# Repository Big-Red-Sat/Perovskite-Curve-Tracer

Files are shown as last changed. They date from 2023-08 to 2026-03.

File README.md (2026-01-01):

# Perovskite Curve Tracer
This project contains the hardware and software source for the curve tracer developed to evaluate perovskite solar cell samples during the [Big Red Sat-1 project](https://github.com/Big-Red-Sat/Big-Red-Sat-1).

## Hardware
The hardware is licensed under a CERN Open Hardware Licence Version 2 - Strongly Reciprocal license.  The developed hardware performs a passive curve tracing process that utilizes a low-Ohm resistor ladder, realized through analog switches and precision resistors.  The multiplexing of the perovskite solar cells is achieved through a low-Ohm analog SPDT relay.  Provisions are also made for an I2C connection to a temperature sensor on the sample holder.  A simple control interface is provisioned through USB for controlling the hardware and retrieve readings.

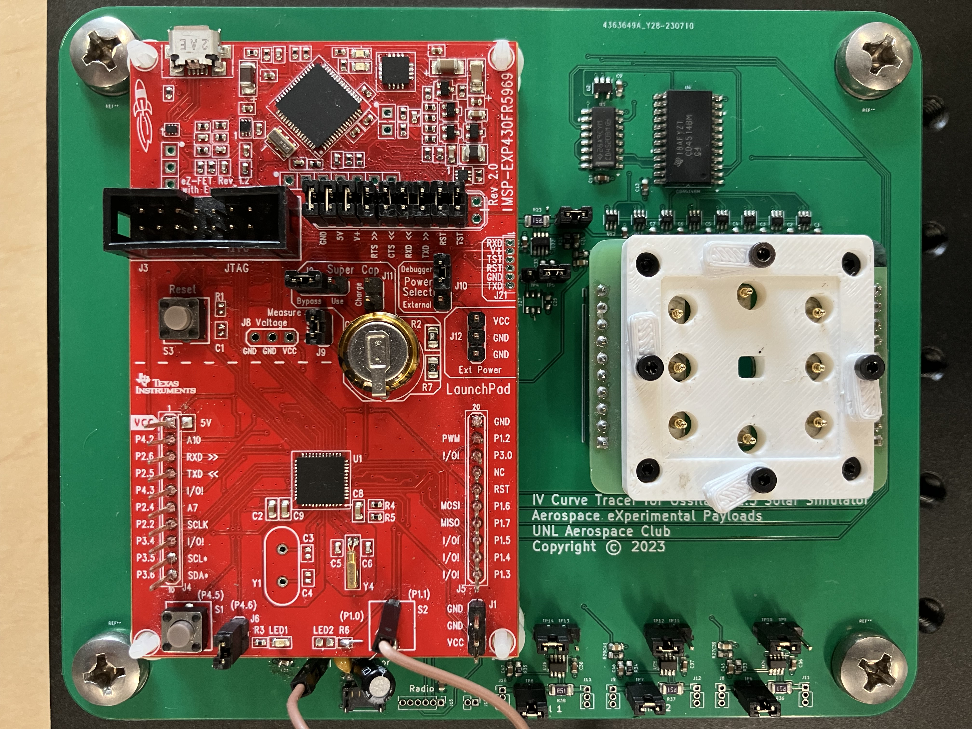
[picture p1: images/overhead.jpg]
Overhead hardware


## Software
The software is licensed under an MIT license.  The software is operated using a single Python script under the software directory, `curve_tracer.py`.  
1. Clone this repository to a local directory,
2. Create a Python 3.9 virtual environment in the software folder,
3. Install all packages using the requirements.txt file,
4. Run curve_tracer.py.

## Performance
The collected data can be saved to the software folder under a directory called curves.  In that folder are numerous experiments from the Big Red Sat-1 project.  The plotted curves will look like the image below.
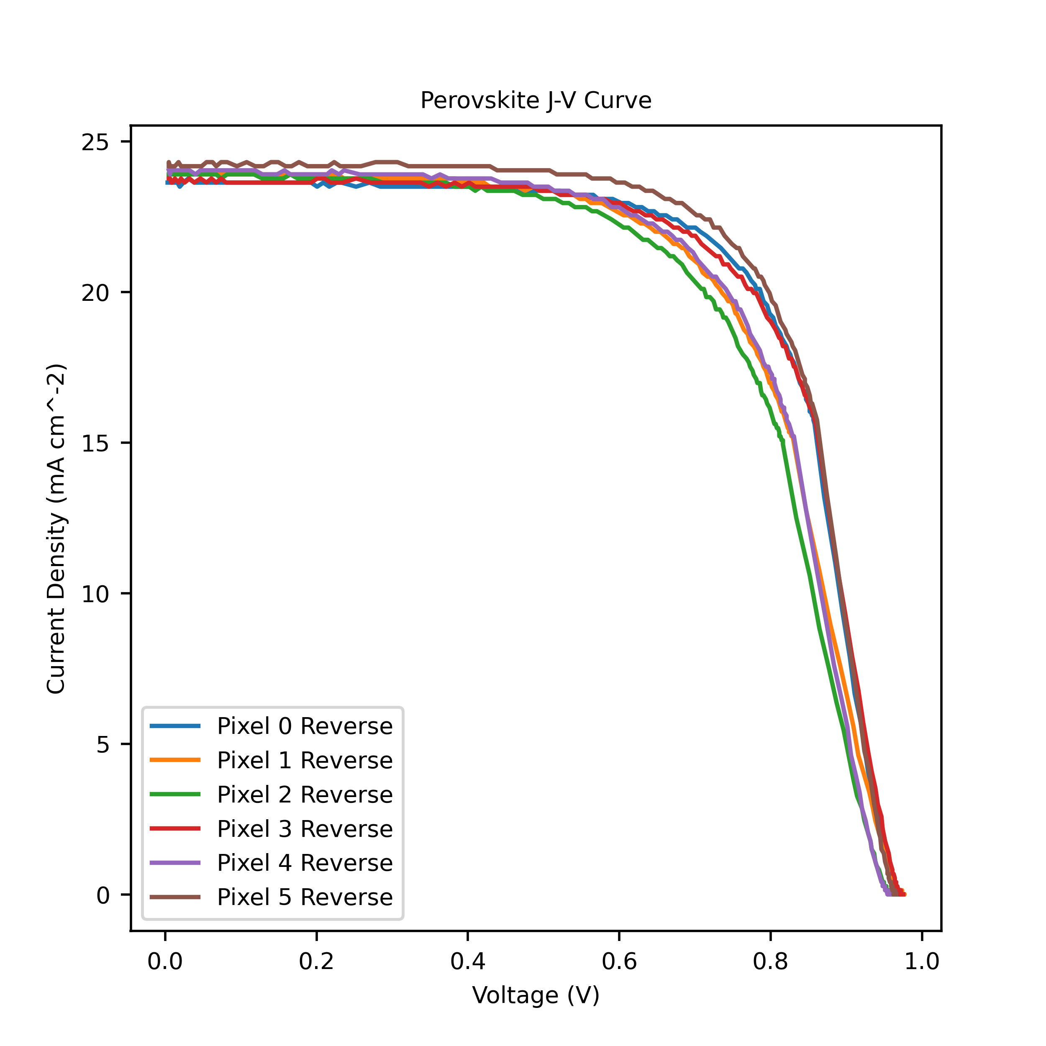
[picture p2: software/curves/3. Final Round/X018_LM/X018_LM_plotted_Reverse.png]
X018 Curve


## Citation
If this repository was useful to your research, then please cite this repository using the BibTeX definition below.
```
@software{
  Arce_Perovskite_Curve_Tracer_2023,
  author = {Arce, Walker},
  month = aug,
  title = {{Perovskite Curve Tracer}},
  url = {https://github.com/wsarce/Perovskite-Curve-Tracer},
  version = {v1.0.0},
  year = {2023}
}
```
## Contact
For additional information or questions, please contact Walker Arce (wsarcera@gmail.com).

## License
The hardware is licensed under a CERN Open Hardware Licence Version 2 - Strongly Reciprocal, the software and firmware is licensed under an MIT license, and the documentation is licensed under a Creative Commons Attribution-ShareAlike 4.0 International Public License.

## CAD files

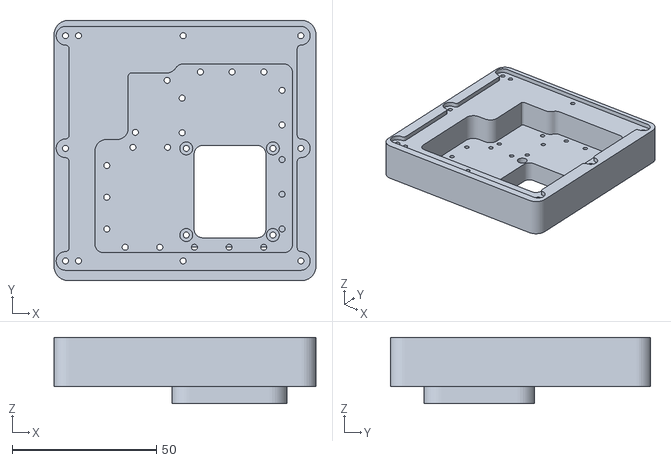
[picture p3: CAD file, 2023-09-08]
hardware/cell holder/Holder/payload_holder_p2.stl
90.7 x 90.2 x 23.0

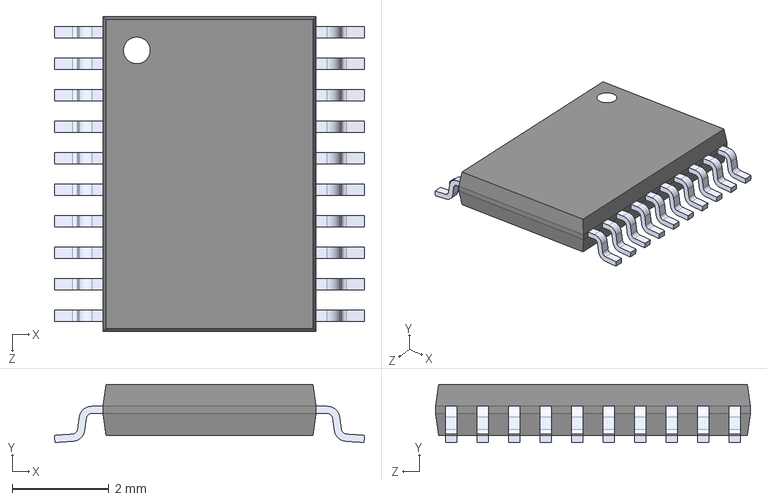
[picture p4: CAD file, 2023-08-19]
hardware/multiplexer cell tester/KiCAD Parts/ADS131M04IPWR/ADS131M04IPWR.step
6.40 x 1.20 x 6.50 mm

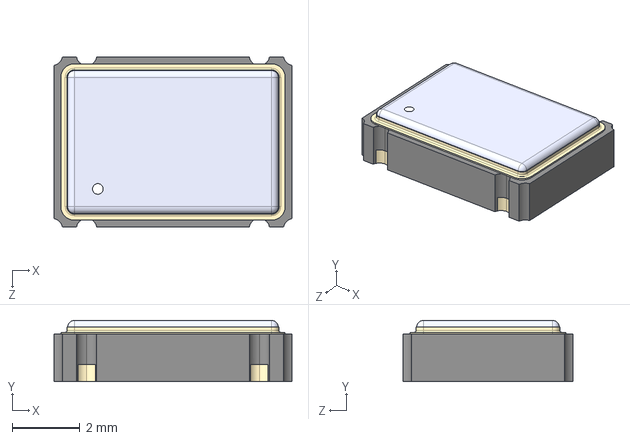
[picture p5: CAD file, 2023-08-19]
hardware/multiplexer cell tester/KiCAD Parts/CB3LV-3I-8M1920/CB3LV-3I-8M1920.step
7.00 x 1.80 x 5.00 mm

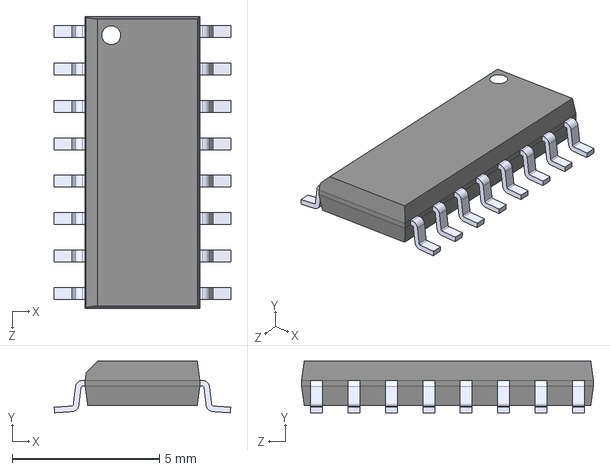
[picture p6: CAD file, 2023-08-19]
hardware/multiplexer cell tester/KiCAD Parts/CD4028BMT/CD4028BMT.step
5.99 x 1.75 x 9.91 mm

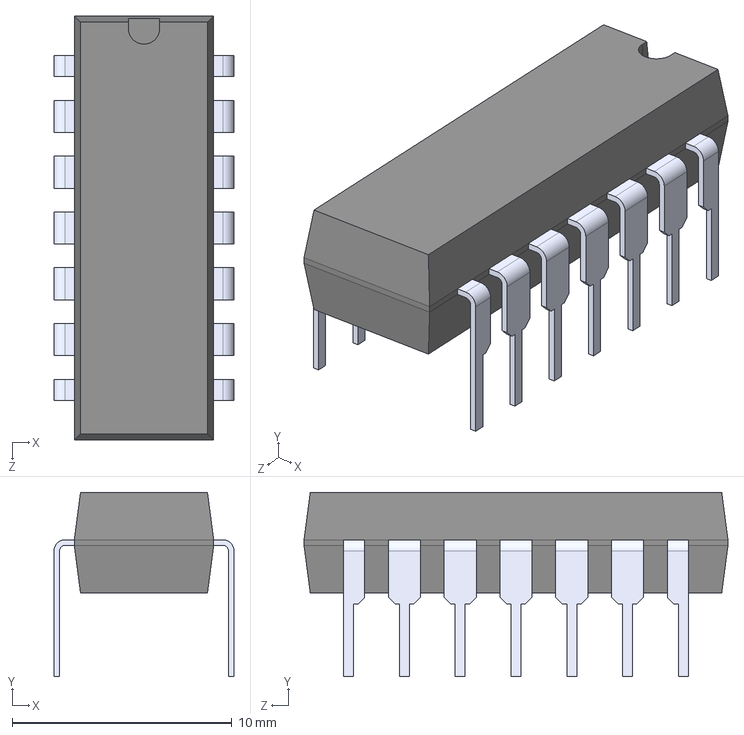
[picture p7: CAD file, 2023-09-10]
hardware/multiplexer cell tester/KiCAD Parts/CD4071BE/CD4071BE.step
8.19 x 8.38 x 19.3 mm

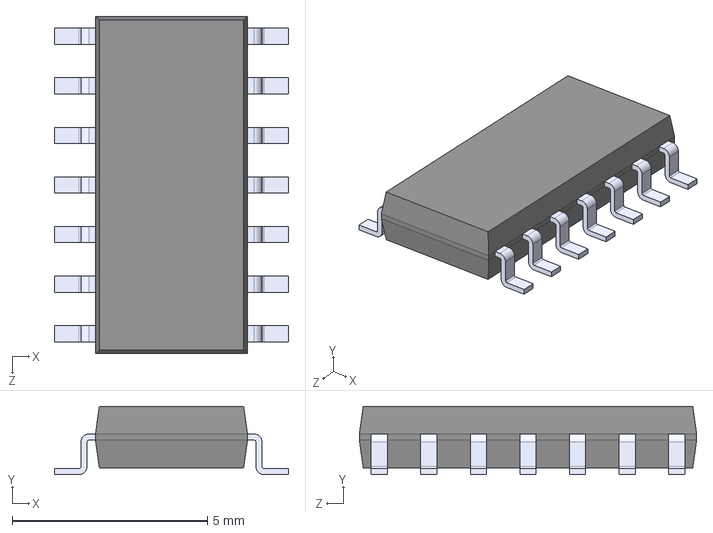
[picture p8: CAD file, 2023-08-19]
hardware/multiplexer cell tester/KiCAD Parts/CD4072BM/CD4072BM.step
6.00 x 1.75 x 8.65 mm

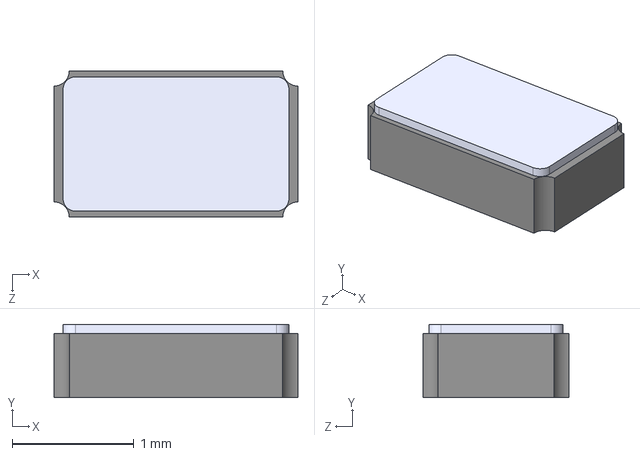
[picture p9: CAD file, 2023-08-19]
hardware/multiplexer cell tester/KiCAD Parts/CM8V-T1A-32.768KHZ-7PF-20PPM-TA-QC/CM8V-T1A-32.768KHZ-7PF-20PPM-TA-QC.step
2.00 x 0.6 x 1.20 mm

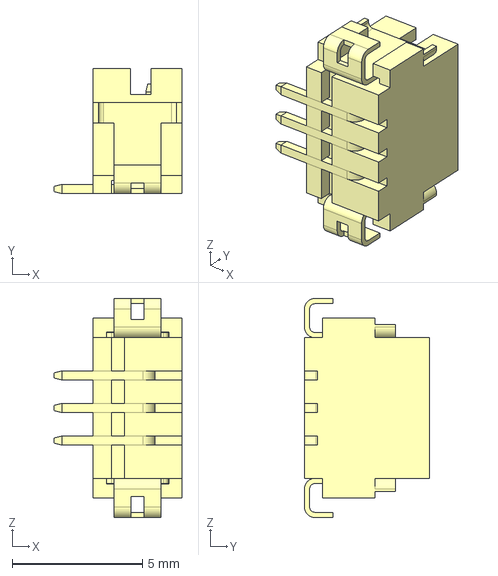
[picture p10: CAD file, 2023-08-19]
hardware/multiplexer cell tester/KiCAD Parts/DF13C-3P-1.25V_21_/WNCW-1600324.stp
4.90 x 4.80 x 8.40 mm

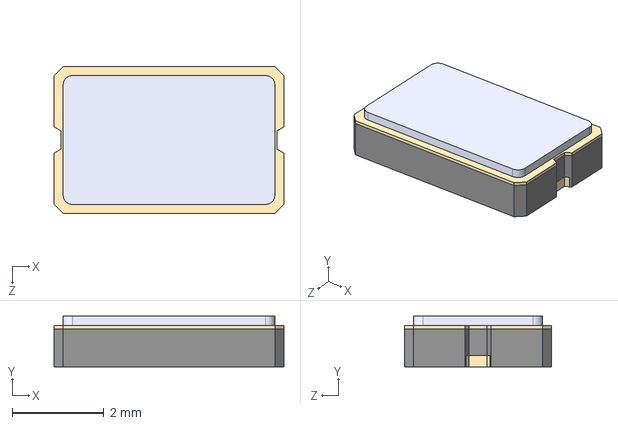
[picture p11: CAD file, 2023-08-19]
hardware/multiplexer cell tester/KiCAD Parts/ECS-81.92-12-30Q-EN-TR/ECS-81.92-12-30Q-EN-TR.step
5.00 x 1.10 x 3.20 mm

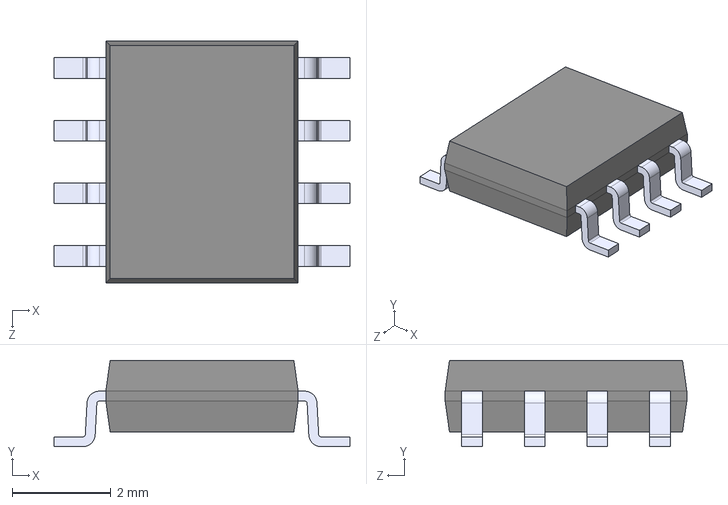
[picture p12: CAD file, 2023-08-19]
hardware/multiplexer cell tester/KiCAD Parts/ICL7660CSAT/ICL7660CSAT.step
6.00 x 1.75 x 4.90 mm

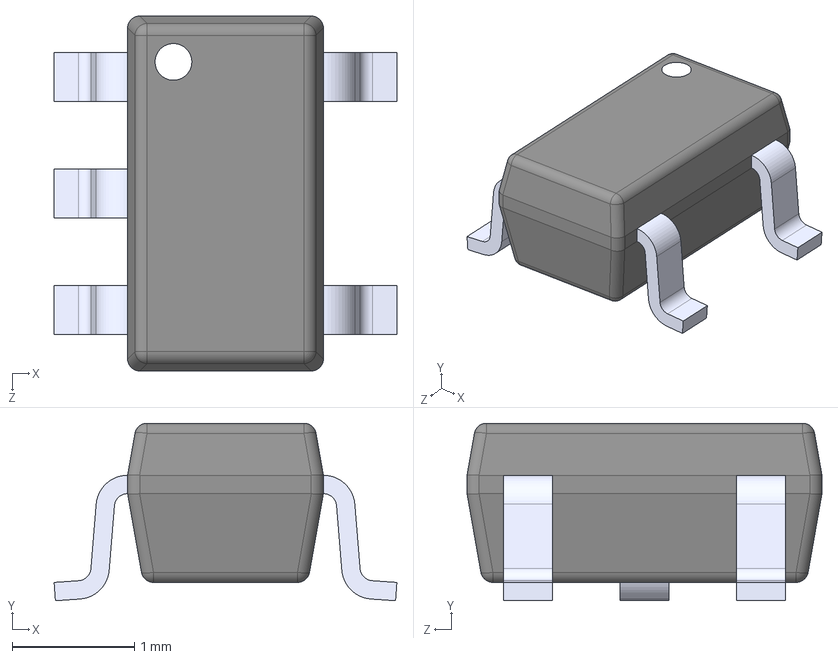
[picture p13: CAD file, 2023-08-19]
hardware/multiplexer cell tester/KiCAD Parts/INA180B2IDBVT/INA180B2IDBVT.step
2.80 x 1.45 x 2.90 mm

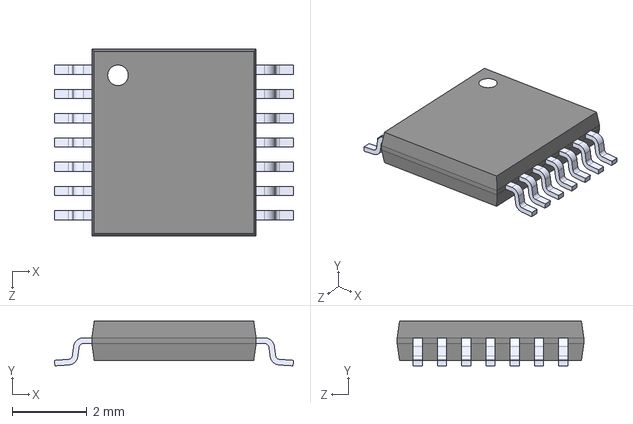
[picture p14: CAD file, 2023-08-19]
hardware/multiplexer cell tester/KiCAD Parts/INA4180A4IPWR/INA4180A4IPWR.step
6.40 x 1.20 x 5.00 mm

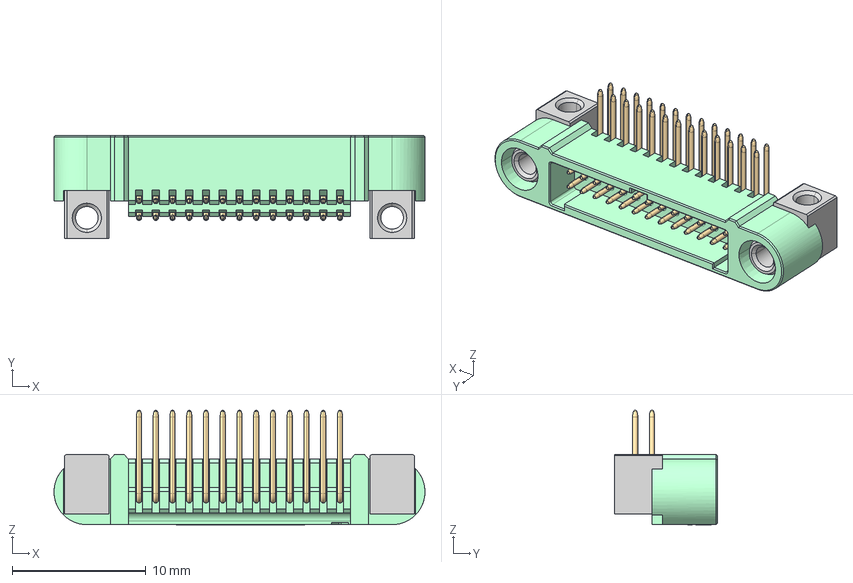
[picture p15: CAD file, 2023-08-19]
hardware/multiplexer cell tester/KiCAD Parts/LIB_G125-MH12605M4R/G125-MH12605M4R.stp
27.7 x 7.70 x 8.55 mm
G125-3272696
G125-4640000 x 2
G125-1060005_BENT x 13
G125-1070005_BENT x 13

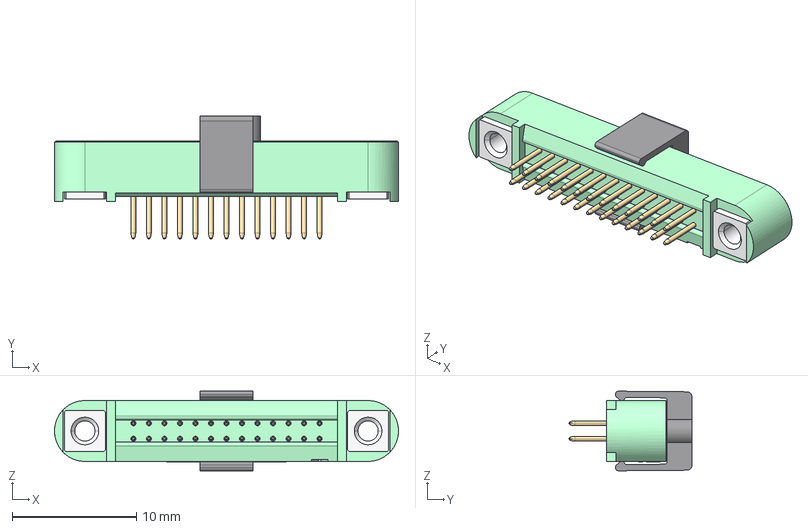
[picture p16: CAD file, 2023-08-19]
hardware/multiplexer cell tester/KiCAD Parts/LIB_G125-MV12605M1P/G125-MV12605M1P.stp
27.7 x 9.90 x 6.41 mm
G125-3212696
G125-1030000 x 26
G125-5000098_CAP_AF5
G125-4620000 x 2
G125_LASER_HARWIN

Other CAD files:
hardware/multiplexer cell tester/KiCAD Parts/LT3092EDD_TRPBF/LT3092EDD_TRPBF.step
hardware/multiplexer cell tester/KiCAD Parts/LT3092ETS8TRPBF/LT3092ETS8TRPBF.step
hardware/multiplexer cell tester/KiCAD Parts/MAX4736EUBT/MAX4736EUBT.step
hardware/multiplexer cell tester/KiCAD Parts/MSP430FR5969IRGZR/MSP430FR5969IRGZR.step
hardware/cell holder/Holder/arm.step
hardware/cell holder/Holder/arm_v2.stl
hardware/cell holder/Holder/body.step
hardware/cell holder/Holder/body_v2.stl
hardware/cell holder/Holder/payload_holder_p1.stl
hardware/cell holder/Holder/payload_holder_p3.stl
hardware/multiplexer cell tester/KiCAD Parts/0781710004/0781710004.step
hardware/multiplexer cell tester/KiCAD Parts/NX3L4051PW_118/NX3L4051PW_118.step
hardware/multiplexer cell tester/KiCAD Parts/ul_ADG841YKSZ-500RL7/SC70-3.iges
hardware/multiplexer cell tester/KiCAD Parts/ul_ADG841YKSZ-500RL7/SC70-3.step
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

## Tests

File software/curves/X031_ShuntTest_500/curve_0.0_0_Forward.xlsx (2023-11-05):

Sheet: Summary
 | 0
Time | 2023-10-22 16:01
ID | X031_ShuntTest_500
Pixel | 0
Pixel Area | 0.058
Irradiance | 100
Panel Temperature | 0
Voc | 0.004820512821
Isc | 2.552036199
Vmp | 0.4675897436
Imp | 1.283894754
Pmp | 0.600336019
FF | 48.79898604
Eff | 0.1035062102
Dir | Forward

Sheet: Data
 | Voltage | Current | Current Density | Power
0 | 0.004820512821 | 2.961622256 | 51.06245269 | 0.01427653805
1 | 0.08837606838 | 2.512652924 | 43.32160215 | 0.2220583867
2 | 0.1638974359 | 2.134573488 | 36.80299116 | 0.3498511213
3 | 0.2265641026 | 1.8352606 | 31.64242414 | 0.4158041708
4 | 0.2795897436 | 1.567454332 | 27.02507469 | 0.4382441548
5 | 0.3245811966 | 1.354784649 | 23.35835602 | 0.4397376225
6 | 0.3631452991 | 1.16574493 | 20.09905053 | 0.4233347915
7 | 0.3952820513 | 1.000335177 | 17.24715822 | 0.3954145407
8 | 0.4242051282 | 0.858555388 | 14.8026791 | 0.3642035984
9 | 0.4483076923 | 0.7482822189 | 12.90141757 | 0.3354606747
10 | 0.4708034188 | 0.6380090498 | 11.00015603 | 0.3003768419
11 | 0.4884786325 | 0.5513658455 | 9.506307681 | 0.2693304342
12 | 0.5061538462 | 0.4804759511 | 8.284068122 | 0.2431947506
13 | 0.519008547 | 0.4095860566 | 7.061828563 | 0.2125786641
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

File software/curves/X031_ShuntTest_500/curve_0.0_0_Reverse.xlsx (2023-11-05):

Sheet: Summary
 | 0
Time | 2023-10-22 16:00
ID | X031_ShuntTest_500
Pixel | 0
Pixel Area | 0.058
Irradiance | 100
Panel Temperature | 0
Voc | 0.006427350427
Isc | 0
Vmp | 0.4322393162
Imp | 1.205128205
Pmp | 0.5209037914
FF | 5209037.914
Eff | 0.08981099851
Dir | Reverse

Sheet: Data
 | Voltage | Current | Current Density | Power
0 | 0.006427350427 | 2.953745601 | 50.92664829 | 0.01898475805
1 | 0.008034188034 | 2.945868946 | 50.79084389 | 0.02366766504
2 | 0.01124786325 | 2.922238981 | 50.38343071 | 0.03286894444
3 | 0.01606837607 | 2.898609016 | 49.97601752 | 0.04657593975
4 | 0.0241025641 | 2.867102397 | 49.43279994 | 0.0691045193
5 | 0.03052991453 | 2.827719122 | 48.75377796 | 0.0863300231
6 | 0.03856410256 | 2.788335847 | 48.07475599 | 0.1075296696
7 | 0.0465982906 | 2.748952572 | 47.39573401 | 0.1280964908
8 | 0.05945299145 | 2.678062678 | 46.17349445 | 0.1592188375
9 | 0.06909401709 | 2.622926094 | 45.22286368 | 0.1812285003
10 | 0.08034188034 | 2.559912854 | 44.13642852 | 0.2056682122
11 | 0.08998290598 | 2.504776269 | 43.18579775 | 0.2253870476
12 | 0.09962393162 | 2.449639685 | 42.23516698 | 0.2440427365
13 | 0.1076581197 | 2.3945031 | 41.28453621 | 0.2577877013
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

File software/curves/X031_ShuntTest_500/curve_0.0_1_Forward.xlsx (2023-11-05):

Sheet: Summary
 | 0
Time | 2023-10-22 16:01
ID | X031_ShuntTest_500
Pixel | 1
Pixel Area | 0.058
Irradiance | 100
Panel Temperature | 0
Voc | 0.6475555556
Isc | 2.599296129
Vmp | 0.5093675214
Imp | 1.291771409
Pmp | 0.657986401
FF | 0.390916587
Eff | 0.1134459312
Dir | Forward

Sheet: Data
 | Voltage | Current | Current Density | Power
0 | 0.6475555556 | 0.03150661974 | 0.5432175818 | 0.02040228665
1 | 0.6491623932 | 0.03150661974 | 0.5432175818 | 0.02045291267
2 | 0.6523760684 | 0.02362996481 | 0.4074131863 | 0.01541562354
3 | 0.653982906 | 0.02362996481 | 0.4074131863 | 0.01545359305
4 | 0.6571965812 | 0.01575330987 | 0.2716087909 | 0.01035302139
5 | 0.6588034188 | 0.02362996481 | 0.4074131863 | 0.0155675016
6 | 0.6604102564 | 0.02362996481 | 0.4074131863 | 0.01560547112
7 | 0.662017094 | 0.01575330987 | 0.2716087909 | 0.01042896042
8 | 0.6636239316 | 0.01575330987 | 0.2716087909 | 0.01045427343
9 | 0.6652307692 | 0.01575330987 | 0.2716087909 | 0.01047958644
10 | 0.6668376068 | 0.007876654935 | 0.1358043954 | 0.005252449727
11 | 0.6668376068 | 0.007876654935 | 0.1358043954 | 0.005252449727
12 | 0.6684444444 | 0.007876654935 | 0.1358043954 | 0.005265106232
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

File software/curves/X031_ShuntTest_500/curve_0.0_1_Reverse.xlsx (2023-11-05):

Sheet: Summary
 | 0
Time | 2023-10-22 16:00
ID | X031_ShuntTest_500
Pixel | 1
Pixel Area | 0.058
Irradiance | 100
Panel Temperature | 0
Voc | 0.006427350427
Isc | 0
Vmp | 0.4949059829
Imp | 1.220881515
Pmp | 0.6042215662
FF | 6042215.662
Eff | 0.1041761321
Dir | Reverse

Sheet: Data
 | Voltage | Current | Current Density | Power
0 | 0.006427350427 | 2.922238981 | 50.38343071 | 0.01878225396
1 | 0.008034188034 | 2.914362326 | 50.24762631 | 0.02341453493
2 | 0.01285470085 | 2.898609016 | 49.97601752 | 0.0372607518
3 | 0.01767521368 | 2.874979051 | 49.56860434 | 0.05081586905
4 | 0.0241025641 | 2.835595777 | 48.88958236 | 0.06834512898
5 | 0.03052991453 | 2.804089157 | 48.34636478 | 0.0856086023
6 | 0.03695726496 | 2.764705882 | 47.6673428 | 0.1021759678
7 | 0.0465982906 | 2.717445953 | 46.85251643 | 0.1266283362
8 | 0.05784615385 | 2.654432713 | 45.76608126 | 0.1535487231
9 | 0.06748717949 | 2.591419474 | 44.6796461 | 0.1748875912
10 | 0.07873504274 | 2.528406234 | 43.59321094 | 0.1990741729
11 | 0.08837606838 | 2.47326965 | 42.64258017 | 0.2185778477
12 | 0.09801709402 | 2.418133065 | 41.6919494 | 0.237018376
13 | 0.1060512821 | 2.362996481 | 40.74131863 | 0.2505988063
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

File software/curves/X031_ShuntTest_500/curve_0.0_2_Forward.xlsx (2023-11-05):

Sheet: Summary
 | 0
Time | 2023-10-22 16:01
ID | X031_ShuntTest_500
Pixel | 2
Pixel Area | 0.058
Irradiance | 100
Panel Temperature | 0
Voc | 0.6330940171
Isc | 2.615049439
Vmp | 0.4788376068
Imp | 1.268141445
Pmp | 0.6072338145
FF | 0.3667818261
Eff | 0.1046954853
Dir | Forward

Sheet: Data
 | Voltage | Current | Current Density | Power
0 | 0.6330940171 | 0 | 0 | 0
1 | 0.6314871795 | 0 | 0 | 0
2 | 0.6298803419 | 0 | 0 | 0
3 | 0.6298803419 | 0 | 0 | 0
4 | 0.6298803419 | 0 | 0 | 0
5 | 0.6298803419 | 0 | 0 | 0
6 | 0.6282735043 | 0 | 0 | 0
7 | 0.6282735043 | 0.007876654935 | 0.1358043954 | 0.004948693598
8 | 0.6282735043 | 0 | 0 | 0
9 | 0.6282735043 | 0 | 0 | 0
10 | 0.6282735043 | 0 | 0 | 0
11 | 0.6282735043 | 0 | 0 | 0
12 | 0.6282735043 | 0 | 0 | 0
13 | 0.6282735043 | 0 | 0 | 0
14 | 0.6282735043 | 0 | 0 | 0
15 | 0.6282735043 | 0.007876654935 | 0.1358043954 | 0.004948693598
16 | 0.6298803419 | 0 | 0 | 0
17 | 0.6282735043 | 0 | 0 | 0
18 | 0.6282735043 | 0 | 0 | 0
19 | 0.6298803419 | 0 | 0 | 0
20 | 0.6298803419 | 0 | 0 | 0
21 | 0.6298803419 | 0 | 0 | 0
22 | 0.6298803419 | 0 | 0 | 0
23 | 0.6298803419 | 0 | 0 | 0
24 | 0.6298803419 | 0 | 0 | 0
25 | 0.6298803419 | 0 | 0 | 0
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

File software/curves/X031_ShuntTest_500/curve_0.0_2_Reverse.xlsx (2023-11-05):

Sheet: Summary
 | 0
Time | 2023-10-22 16:00
ID | X031_ShuntTest_500
Pixel | 2
Pixel Area | 0.058
Irradiance | 100
Panel Temperature | 0
Voc | 0.006427350427
Isc | 0
Vmp | 0.4531282051
Imp | 1.21300486
Pmp | 0.5496467151
FF | 5496467.151
Eff | 0.09476667501
Dir | Reverse

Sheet: Data
 | Voltage | Current | Current Density | Power
0 | 0.006427350427 | 2.945868946 | 50.79084389 | 0.01893413203
1 | 0.009641025641 | 2.937992291 | 50.6550395 | 0.02832525901
2 | 0.01124786325 | 2.922238981 | 50.38343071 | 0.03286894444
3 | 0.01767521368 | 2.890732361 | 49.84021313 | 0.05109431216
4 | 0.0241025641 | 2.867102397 | 49.43279994 | 0.0691045193
5 | 0.03213675214 | 2.827719122 | 48.75377796 | 0.09087370853
6 | 0.03856410256 | 2.788335847 | 48.07475599 | 0.1075296696
7 | 0.0465982906 | 2.756829227 | 47.5315384 | 0.1284635295
8 | 0.05784615385 | 2.685939333 | 46.30929884 | 0.1553712599
9 | 0.06909401709 | 2.630802748 | 45.35866808 | 0.1817727301
10 | 0.08034188034 | 2.575666164 | 44.40803731 | 0.2069338627
11 | 0.08998290598 | 2.520529579 | 43.45740654 | 0.2268045762
12 | 0.1012307692 | 2.465392995 | 42.50677577 | 0.2495736293
13 | 0.1092649573 | 2.41025641 | 41.556145 | 0.2633565637
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

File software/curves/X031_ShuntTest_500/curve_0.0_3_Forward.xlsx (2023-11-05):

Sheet: Summary
 | 0
Time | 2023-10-22 16:01
ID | X031_ShuntTest_500
Pixel | 3
Pixel Area | 0.058
Irradiance | 100
Panel Temperature | 0
Voc | 0.4804444444
Isc | 1.961287079
Vmp | 0.151042735
Imp | 1.26026479
Pmp | 0.1903538407
FF | 0.2020120402
Eff | 0.03281962771
Dir | Forward

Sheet: Data
 | Voltage | Current | Current Density | Power
0 | 0.4804444444 | 0 | 0 | 0
1 | 0.474017094 | 0.007876654935 | 0.1358043954 | 0.003733669083
2 | 0.4691965812 | 0 | 0 | 0
3 | 0.465982906 | 0 | 0 | 0
4 | 0.4611623932 | 0 | 0 | 0
5 | 0.4579487179 | 0 | 0 | 0
6 | 0.4547350427 | 0 | 0 | 0
7 | 0.4531282051 | 0 | 0 | 0
8 | 0.4515213675 | 0 | 0 | 0
9 | 0.4499145299 | 0 | 0 | 0
10 | 0.4483076923 | 0 | 0 | 0
11 | 0.4467008547 | 0 | 0 | 0
12 | 0.4467008547 | 0 | 0 | 0
13 | 0.4450940171 | 0 | 0 | 0
14 | 0.4434871795 | 0 | 0 | 0
15 | 0.4434871795 | 0.007876654935 | 0.1358043954 | 0.003493195481
16 | 0.4434871795 | 0 | 0 | 0
17 | 0.4418803419 | 0 | 0 | 0
18 | 0.4418803419 | 0 | 0 | 0
19 | 0.4418803419 | 0 | 0 | 0
20 | 0.4418803419 | 0 | 0 | 0
21 | 0.4402735043 | 0.007876654935 | 0.1358043954 | 0.00346788247
22 | 0.4402735043 | 0 | 0 | 0
23 | 0.4402735043 | 0 | 0 | 0
24 | 0.4402735043 | 0 | 0 | 0
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

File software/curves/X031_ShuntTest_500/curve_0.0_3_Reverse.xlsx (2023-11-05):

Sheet: Summary
 | 0
Time | 2023-10-22 16:00
ID | X031_ShuntTest_500
Pixel | 3
Pixel Area | 0.058
Irradiance | 100
Panel Temperature | 0
Voc | 0.004820512821
Isc | 0
Vmp | 0.1462222222
Imp | 1.19725155
Pmp | 0.1750647822
FF | 1750647.822
Eff | 0.03018358314
Dir | Reverse

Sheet: Data
 | Voltage | Current | Current Density | Power
0 | 0.004820512821 | 2.3945031 | 41.28453621 | 0.01154273289
1 | 0.006427350427 | 2.370873136 | 40.87712303 | 0.01523843246
2 | 0.009641025641 | 2.339366516 | 40.33390545 | 0.02255389256
3 | 0.01285470085 | 2.299983241 | 39.65488347 | 0.02956559654
4 | 0.01767521368 | 2.252723312 | 38.8400571 | 0.03981736588
5 | 0.0224957265 | 2.213340037 | 38.16103512 | 0.04979069211
6 | 0.02892307692 | 2.166080107 | 37.34620875 | 0.06264970156
7 | 0.03535042735 | 2.118820178 | 36.53138237 | 0.07490119876
8 | 0.04177777778 | 2.055806938 | 35.44494721 | 0.08588704542
9 | 0.05141880342 | 2.000670354 | 34.49431644 | 0.1028720756
10 | 0.05784615385 | 1.937657114 | 33.40788128 | 0.1120860115
11 | 0.06588034188 | 1.88252053 | 32.45725051 | 0.1240210961
12 | 0.0707008547 | 1.8352606 | 31.64242414 | 0.129754493
13 | 0.07712820513 | 1.780124015 | 30.69179337 | 0.1372977702
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

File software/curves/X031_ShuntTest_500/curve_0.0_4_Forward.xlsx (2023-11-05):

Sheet: Summary
 | 0
Time | 2023-10-22 16:01
ID | X031_ShuntTest_500
Pixel | 4
Pixel Area | 0.058
Irradiance | 100
Panel Temperature | 0
Voc | 0.4370598291
Isc | 1.961287079
Vmp | 0.1397948718
Imp | 1.354784649
Pmp | 0.1893919463
FF | 0.2209425681
Eff | 0.03265378385
Dir | Forward

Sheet: Data
 | Voltage | Current | Current Density | Power
0 | 0.4370598291 | 0 | 0 | 0
1 | 0.4370598291 | 0 | 0 | 0
2 | 0.4370598291 | 0.007876654935 | 0.1358043954 | 0.00344256946
3 | 0.4370598291 | 0 | 0 | 0
4 | 0.4370598291 | 0 | 0 | 0
5 | 0.4370598291 | 0 | 0 | 0
6 | 0.4370598291 | 0 | 0 | 0
7 | 0.4370598291 | 0 | 0 | 0
8 | 0.4370598291 | 0 | 0 | 0
9 | 0.4370598291 | 0 | 0 | 0
10 | 0.4370598291 | 0 | 0 | 0
11 | 0.4370598291 | 0 | 0 | 0
12 | 0.4386666667 | 0 | 0 | 0
13 | 0.4370598291 | 0 | 0 | 0
14 | 0.4370598291 | 0 | 0 | 0
15 | 0.4370598291 | 0 | 0 | 0
16 | 0.4370598291 | 0 | 0 | 0
17 | 0.4370598291 | 0 | 0 | 0
18 | 0.4370598291 | 0 | 0 | 0
19 | 0.4370598291 | 0 | 0 | 0
20 | 0.4370598291 | 0 | 0 | 0
21 | 0.4370598291 | 0 | 0 | 0
22 | 0.4370598291 | 0 | 0 | 0
23 | 0.4370598291 | 0 | 0 | 0
24 | 0.4370598291 | 0 | 0 | 0
25 | 0.4386666667 | 0 | 0 | 0
26 | 0.4386666667 | 0 | 0 | 0
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

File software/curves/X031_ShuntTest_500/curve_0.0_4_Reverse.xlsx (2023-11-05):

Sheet: Summary
 | 0
Time | 2023-10-22 16:00
ID | X031_ShuntTest_500
Pixel | 4
Pixel Area | 0.058
Irradiance | 100
Panel Temperature | 0
Voc | 0.004820512821
Isc | 0
Vmp | 0.1381880342
Imp | 1.268141445
Pmp | 0.1752419733
FF | 1752419.733
Eff | 0.03021413333
Dir | Reverse

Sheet: Data
 | Voltage | Current | Current Density | Power
0 | 0.004820512821 | 2.292106586 | 39.51907907 | 0.01104912918
1 | 0.006427350427 | 2.284229931 | 39.38327468 | 0.01468154623
2 | 0.009641025641 | 2.260599966 | 38.97586149 | 0.02179450224
3 | 0.01285470085 | 2.236970002 | 38.5684483 | 0.02875558019
4 | 0.01767521368 | 2.197586727 | 37.88942633 | 0.03884281497
5 | 0.0224957265 | 2.166080107 | 37.34620875 | 0.04872754566
6 | 0.02892307692 | 2.126696833 | 36.66718677 | 0.06151061608
7 | 0.03535042735 | 2.079436903 | 35.8523604 | 0.07350898317
8 | 0.04338461538 | 2.024300318 | 34.90172963 | 0.08782349074
9 | 0.04981196581 | 1.969163734 | 33.95109886 | 0.09808791659
10 | 0.05784615385 | 1.914027149 | 33.00046809 | 0.1107191089
11 | 0.06588034188 | 1.858890565 | 32.04983732 | 0.1224643459
12 | 0.07230769231 | 1.811630635 | 31.23501095 | 0.1309948305
13 | 0.07712820513 | 1.764370706 | 30.42018458 | 0.1360827457
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

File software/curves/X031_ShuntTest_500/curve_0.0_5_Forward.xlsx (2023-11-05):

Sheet: Summary
 | 0
Time | 2023-10-22 16:01
ID | X031_ShuntTest_500
Pixel | 5
Pixel Area | 0.058
Irradiance | 100
Panel Temperature | 0
Voc | 0.4370598291
Isc | 1.961287079
Vmp | 0.1558632479
Imp | 1.220881515
Pmp | 0.1902905582
FF | 0.2219908789
Eff | 0.03280871693
Dir | Forward

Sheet: Data
 | Voltage | Current | Current Density | Power
0 | 0.4370598291 | 0 | 0 | 0
1 | 0.4370598291 | 0.007876654935 | 0.1358043954 | 0.00344256946
2 | 0.4370598291 | 0 | 0 | 0
3 | 0.4370598291 | 0 | 0 | 0
4 | 0.4370598291 | 0 | 0 | 0
5 | 0.4370598291 | 0 | 0 | 0
6 | 0.4370598291 | 0 | 0 | 0
7 | 0.4370598291 | 0 | 0 | 0
8 | 0.4386666667 | 0 | 0 | 0
9 | 0.4370598291 | 0 | 0 | 0
10 | 0.4370598291 | 0 | 0 | 0
11 | 0.4386666667 | 0 | 0 | 0
12 | 0.4370598291 | 0 | 0 | 0
13 | 0.4386666667 | 0 | 0 | 0
14 | 0.4370598291 | 0 | 0 | 0
15 | 0.4386666667 | 0 | 0 | 0
16 | 0.4370598291 | 0 | 0 | 0
17 | 0.4386666667 | 0 | 0 | 0
18 | 0.4386666667 | 0 | 0 | 0
19 | 0.4386666667 | 0 | 0 | 0
20 | 0.4370598291 | 0 | 0 | 0
21 | 0.4386666667 | 0 | 0 | 0
22 | 0.4370598291 | 0 | 0 | 0
23 | 0.4370598291 | 0 | 0 | 0
24 | 0.4386666667 | 0 | 0 | 0
25 | 0.4386666667 | 0 | 0 | 0
26 | 0.4386666667 | 0 | 0 | 0
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

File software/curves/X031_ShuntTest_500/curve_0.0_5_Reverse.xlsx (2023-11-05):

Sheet: Summary
 | 0
Time | 2023-10-22 16:00
ID | X031_ShuntTest_500
Pixel | 5
Pixel Area | 0.058
Irradiance | 100
Panel Temperature | 0
Voc | 0.004820512821
Isc | 0
Vmp | 0.143008547
Imp | 1.22875817
Pmp | 0.1757229205
FF | 1757229.205
Eff | 0.03029705526
Dir | Reverse

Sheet: Data
 | Voltage | Current | Current Density | Power
0 | 0.004820512821 | 2.292106586 | 39.51907907 | 0.01104912918
1 | 0.006427350427 | 2.284229931 | 39.38327468 | 0.01468154623
2 | 0.009641025641 | 2.260599966 | 38.97586149 | 0.02179450224
3 | 0.01285470085 | 2.236970002 | 38.5684483 | 0.02875558019
4 | 0.01767521368 | 2.197586727 | 37.88942633 | 0.03884281497
5 | 0.0224957265 | 2.166080107 | 37.34620875 | 0.04872754566
6 | 0.02892307692 | 2.126696833 | 36.66718677 | 0.06151061608
7 | 0.03535042735 | 2.087313558 | 35.98816479 | 0.07378742629
8 | 0.04338461538 | 2.024300318 | 34.90172963 | 0.08782349074
9 | 0.04981196581 | 1.969163734 | 33.95109886 | 0.09808791659
10 | 0.05784615385 | 1.914027149 | 33.00046809 | 0.1107191089
11 | 0.06427350427 | 1.86676722 | 32.18564172 | 0.1199836709
12 | 0.0707008547 | 1.811630635 | 31.23501095 | 0.1280838343
13 | 0.07873504274 | 1.764370706 | 30.42018458 | 0.1389178029
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

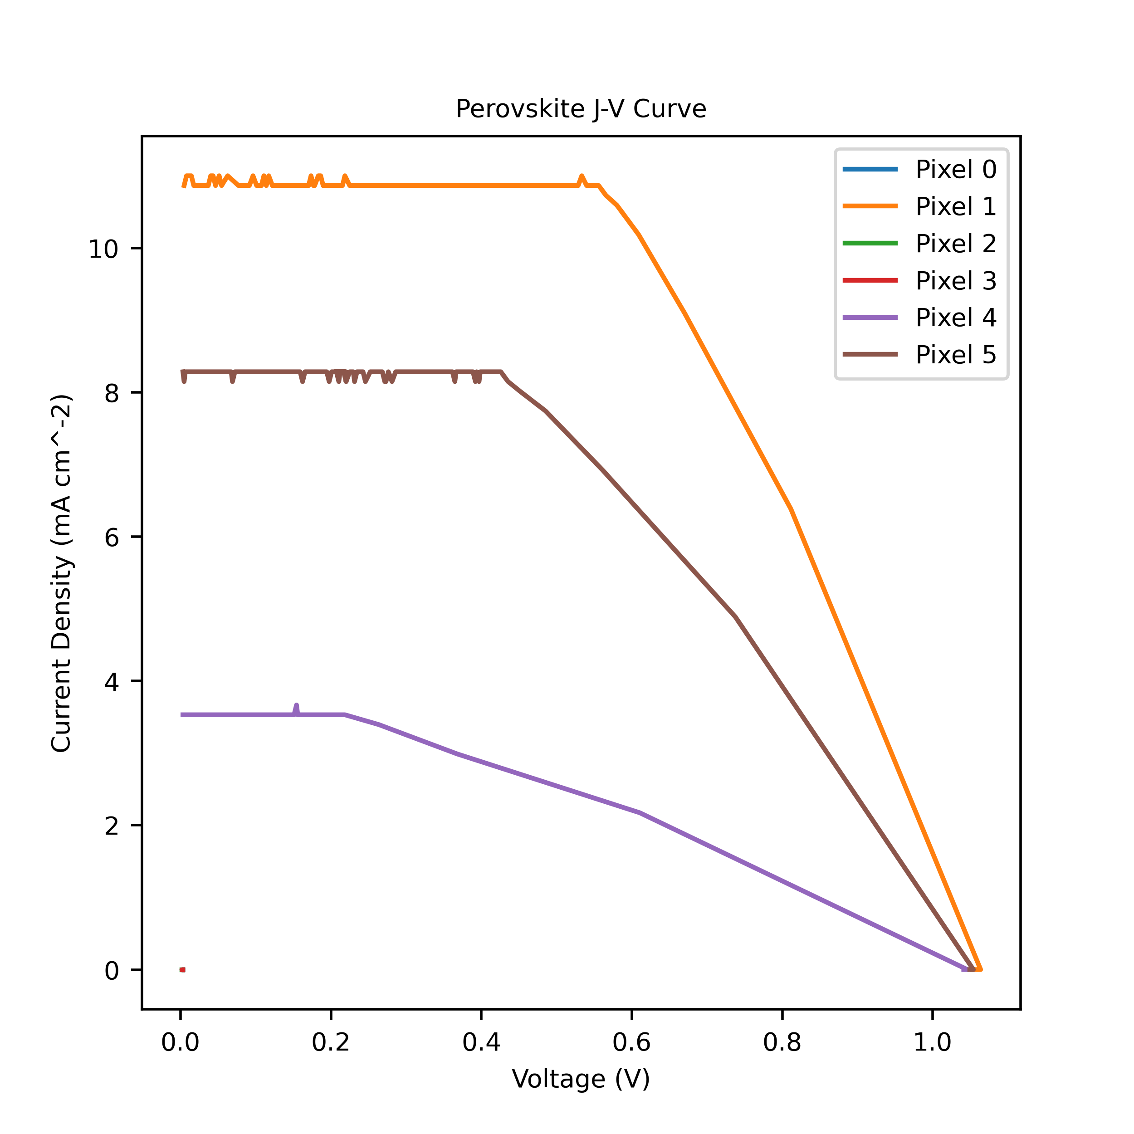
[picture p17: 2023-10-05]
software/curves/2. Round Two/9-9-2023 Payload Test/A031_InPayload2/A031_InPayload2_plotted.png

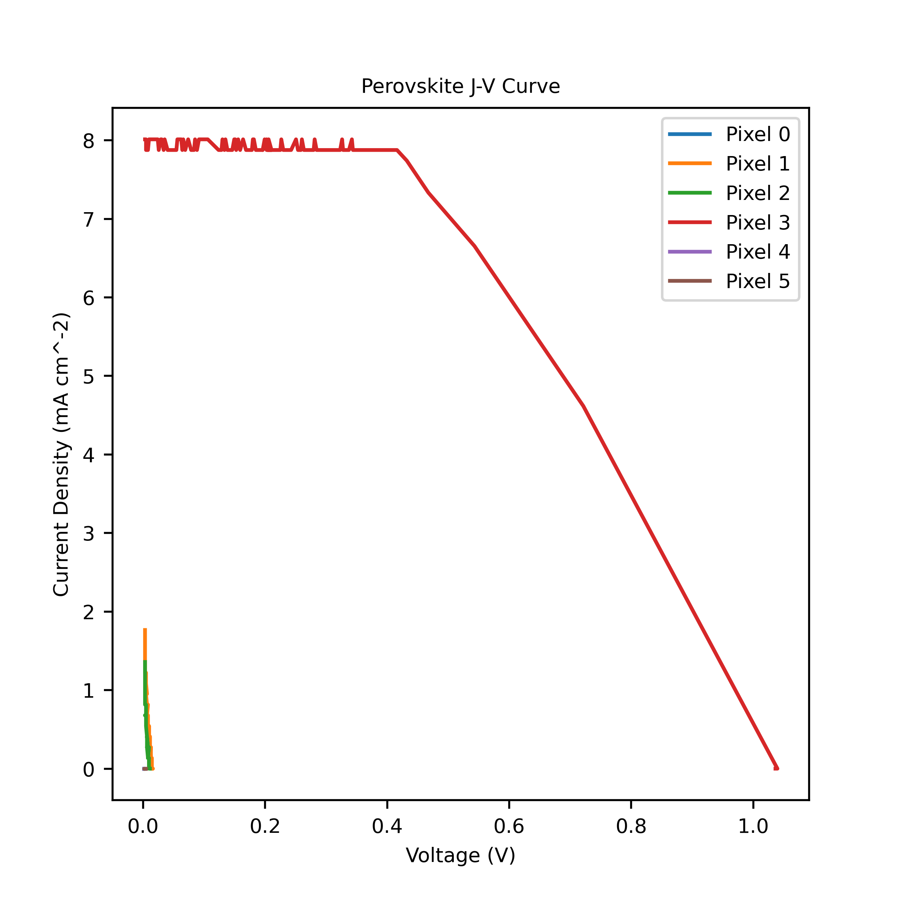
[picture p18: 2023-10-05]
software/curves/2. Round Two/9-9-2023 Payload Test/A037_InPayload2/A037_InPayload2_plotted.png

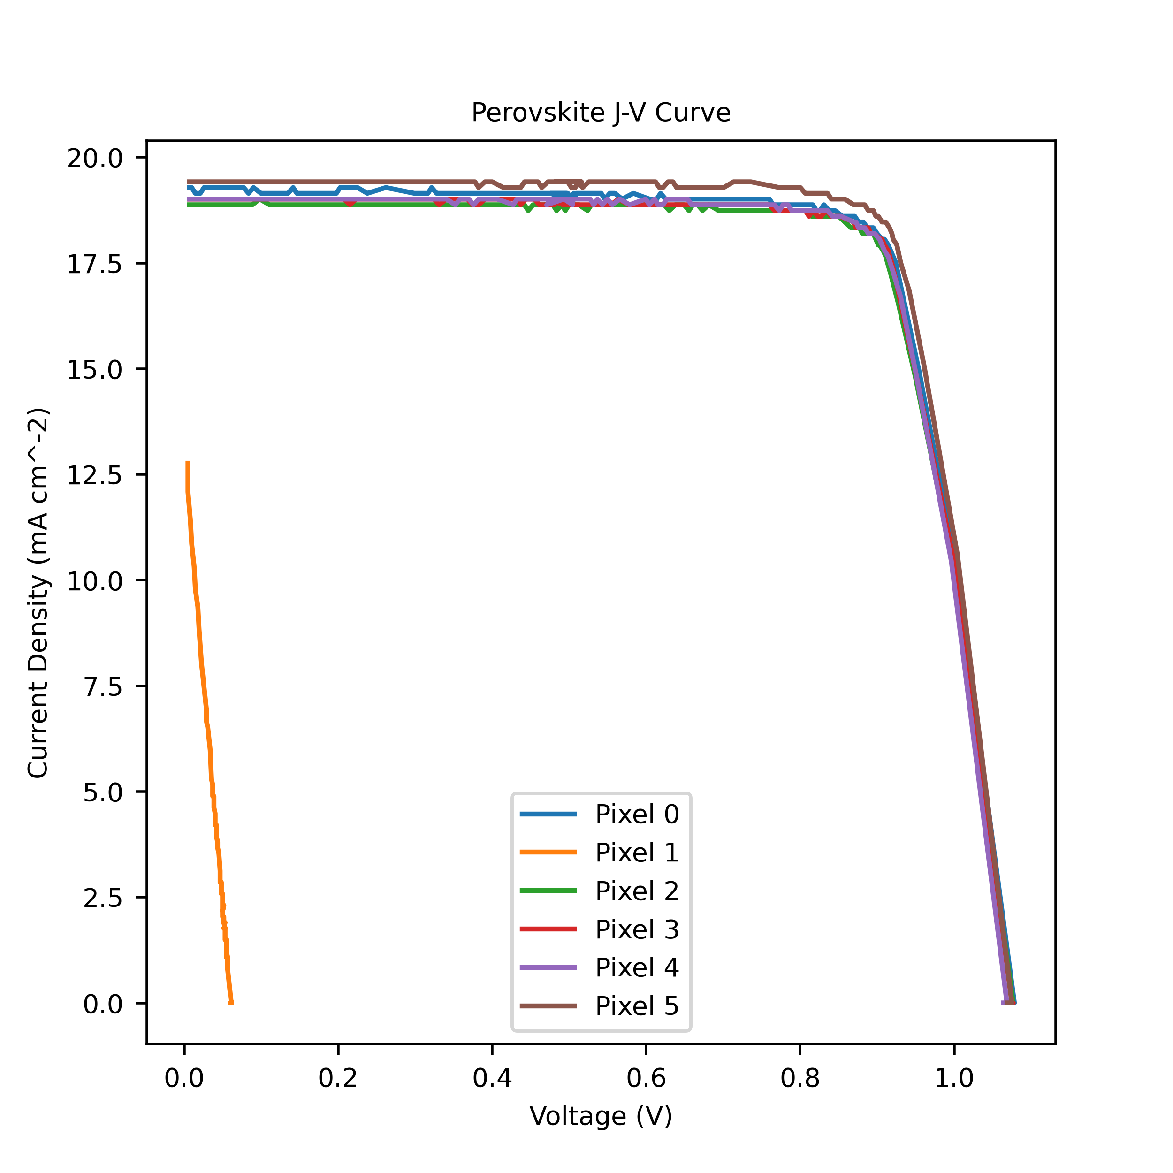
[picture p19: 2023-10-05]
software/curves/2. Round Two/9-9-2023 Payload Test/A031/A031_plotted.png

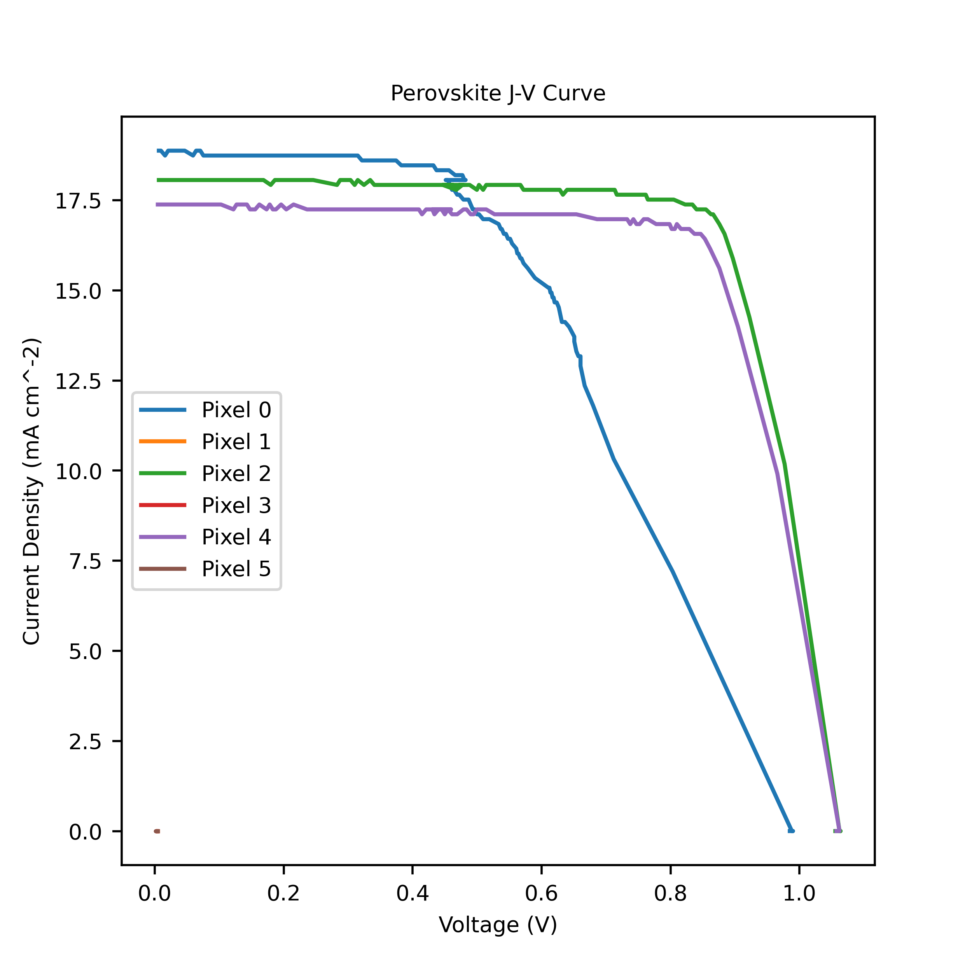
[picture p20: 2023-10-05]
software/curves/2. Round Two/9-9-2023 Payload Test/A027_InPayload2/A027_InPayload2_plotted.png

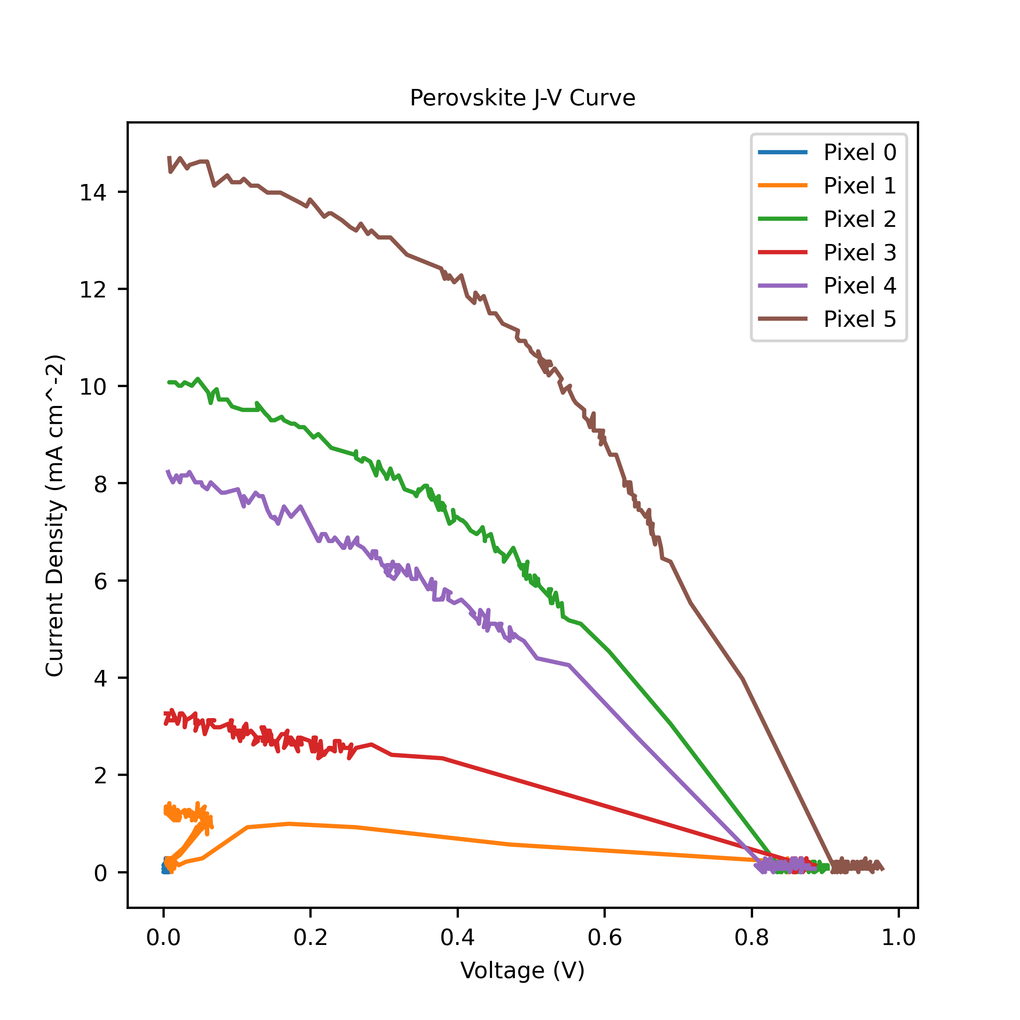
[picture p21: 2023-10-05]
software/curves/1. Round One/1776_test/1776_test_plotted.png

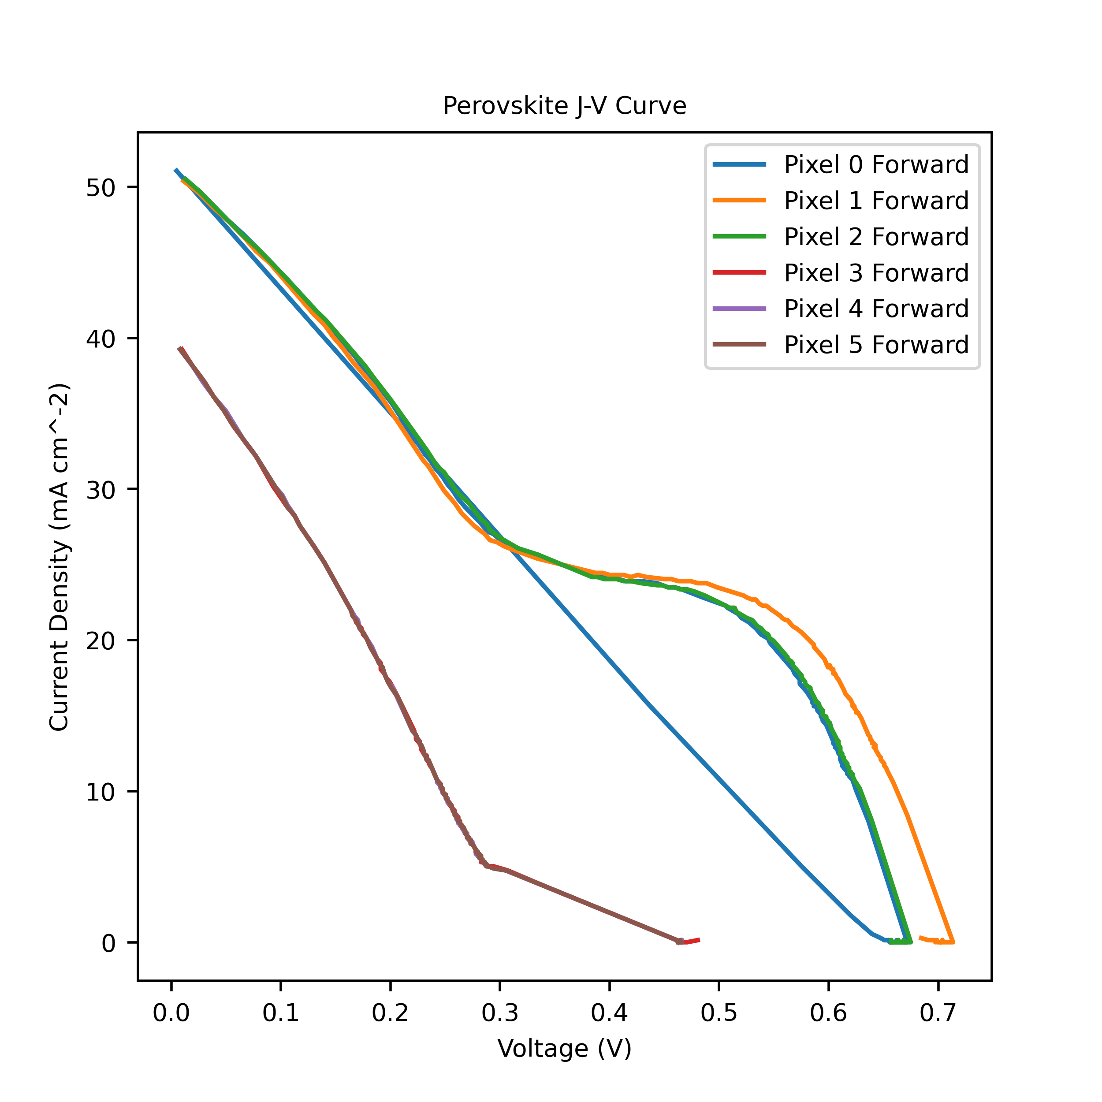
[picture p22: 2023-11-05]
software/curves/X031_ShuntTest_500_LongSettle/X031_ShuntTest_500_LongSettle_plotted_Forward.png

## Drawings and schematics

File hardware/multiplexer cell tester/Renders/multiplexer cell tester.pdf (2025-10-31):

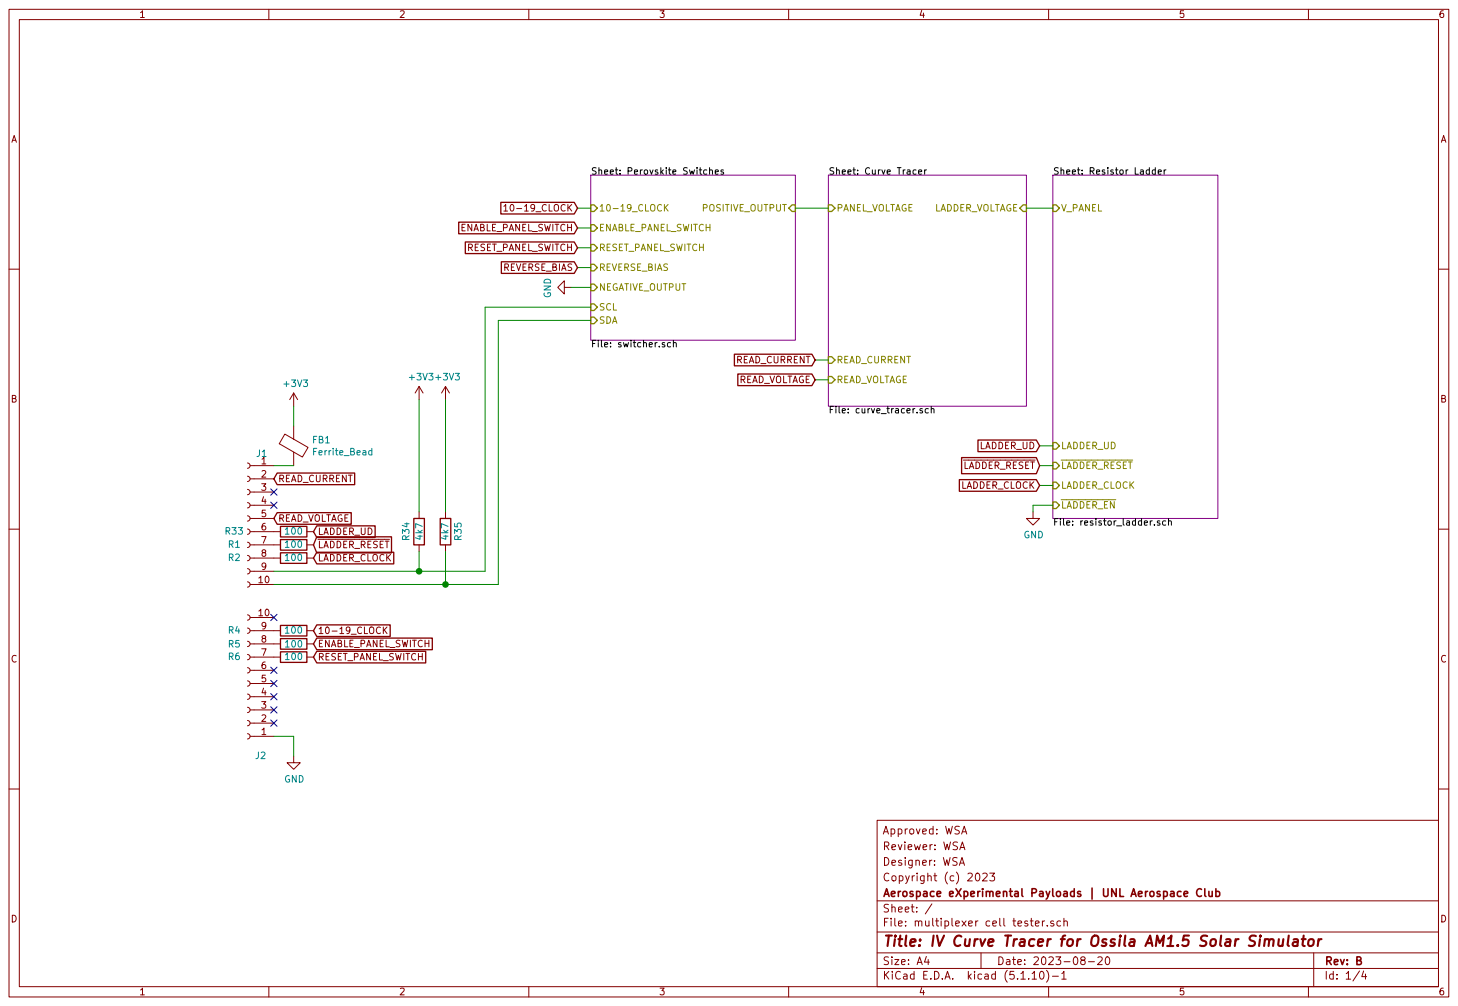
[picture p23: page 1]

Sheet: Resistor Ladder File: resistor_ladder.sch V_PANEL

Approved: WSA
Designer: WSA Reviewer: WSA

Copyright (c) 2023
File: multiplexer cell tester.sch Sheet: / Aerospace eXperimental Payloads | UNL Aerospace Club

Id: 1/4 Title: IV Curve Tracer for Ossila AM1.5 Solar Simulator

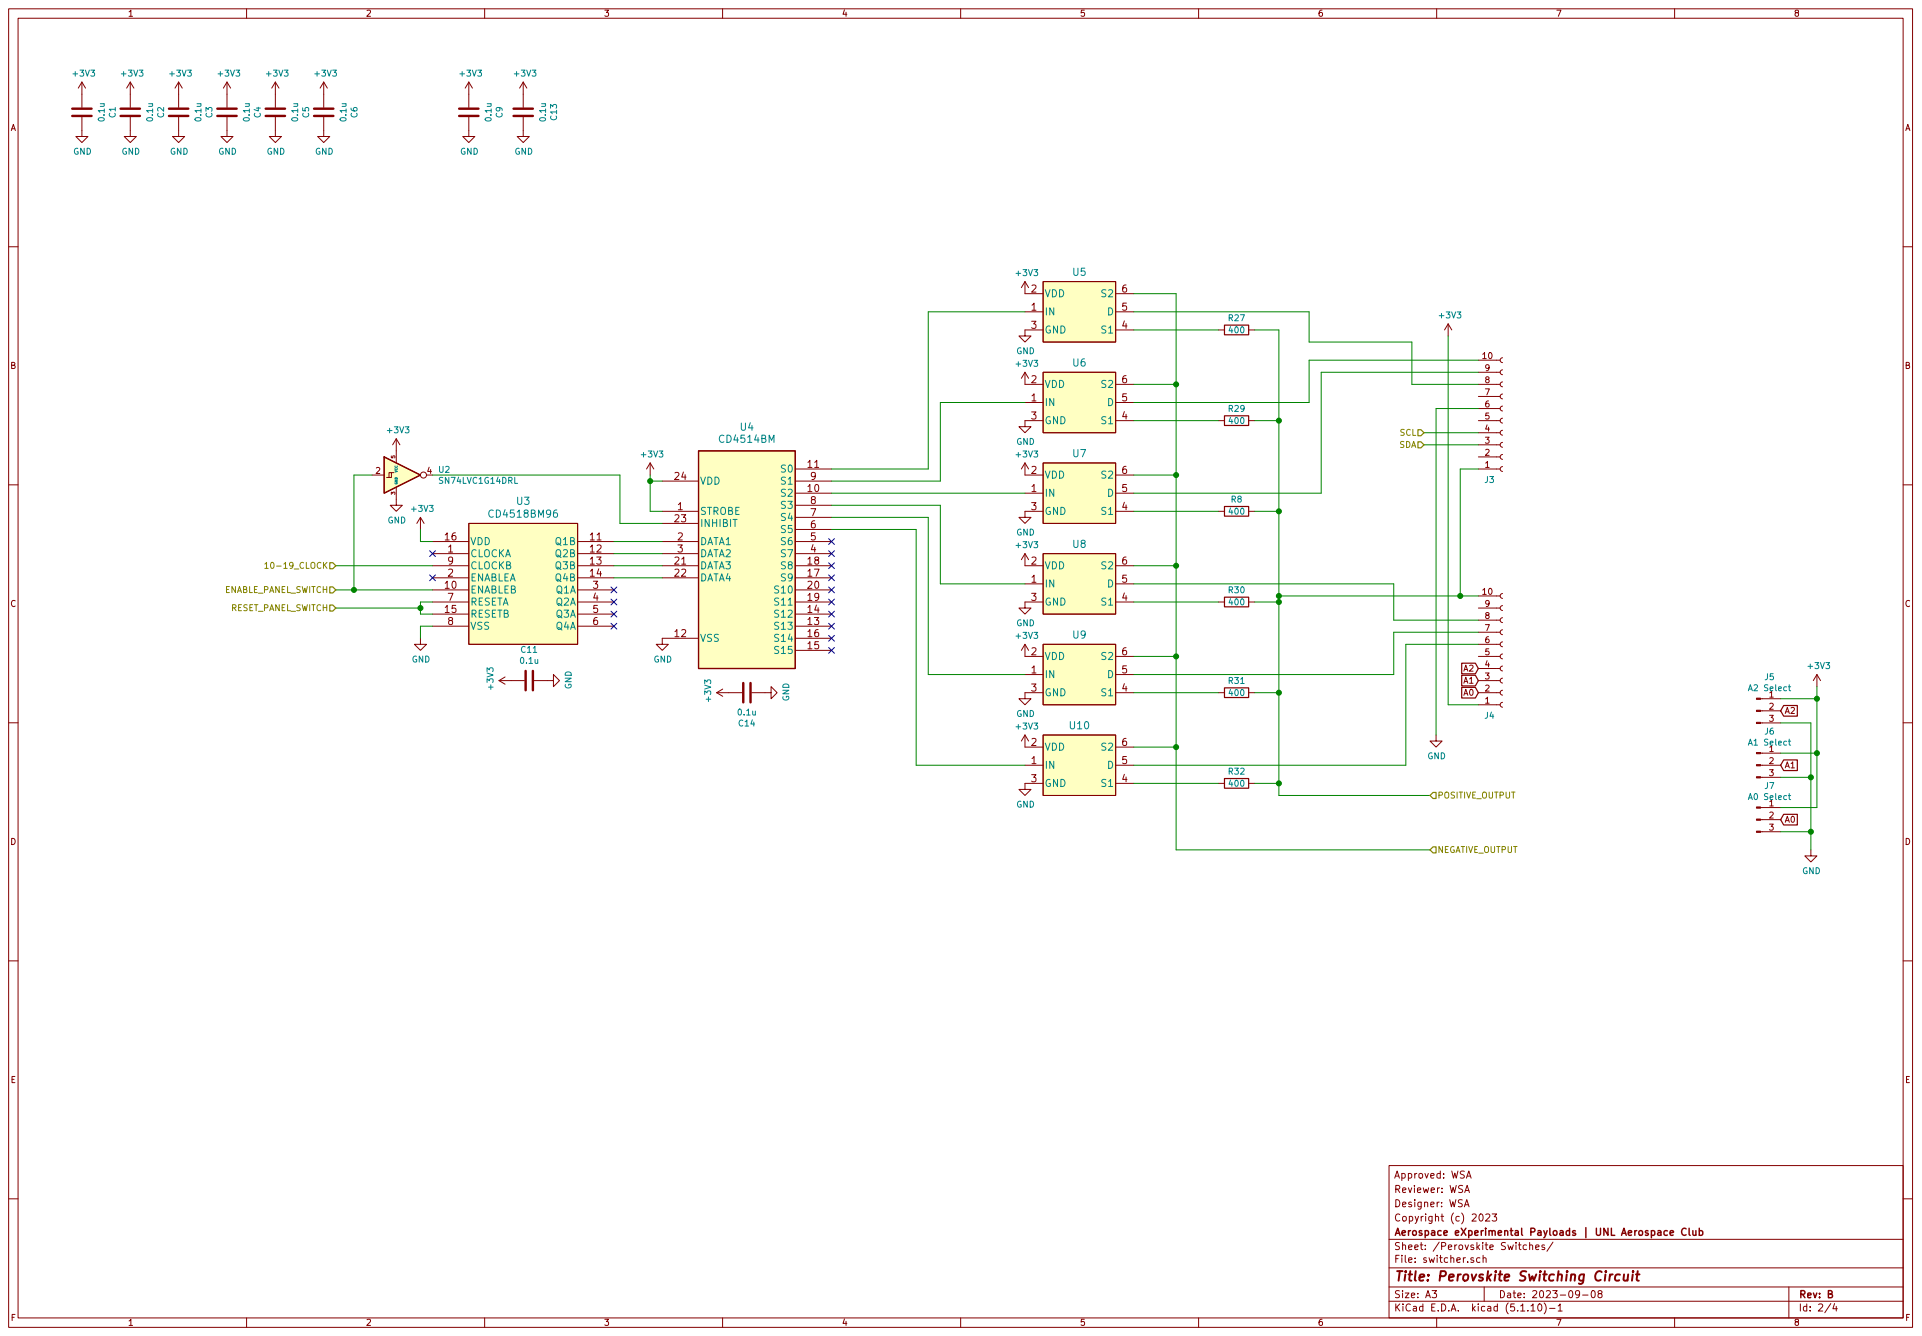
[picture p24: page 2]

5 U2SN74LVC1G14DRL CLOCKA 1 ENABLEB 10 Q1B 11 Q2B 12 Q3B 13 Q4B 14 RESETB 15 VDD 16 ENABLEA 2 Q1A 3 Q2A 4 Q3A 5 Q4A 6 RESETA 7 VSS 8 CLOCKB 9 U3 CD4518BM96 GND

Approved: WSA
Designer: WSA Reviewer: WSA

Copyright (c) 2023
Id: 2/4 Title: Perovskite Switching Circuit File: switcher.sch Sheet: /Perovskite Switches/ Aerospace eXperimental Payloads | UNL Aerospace Club

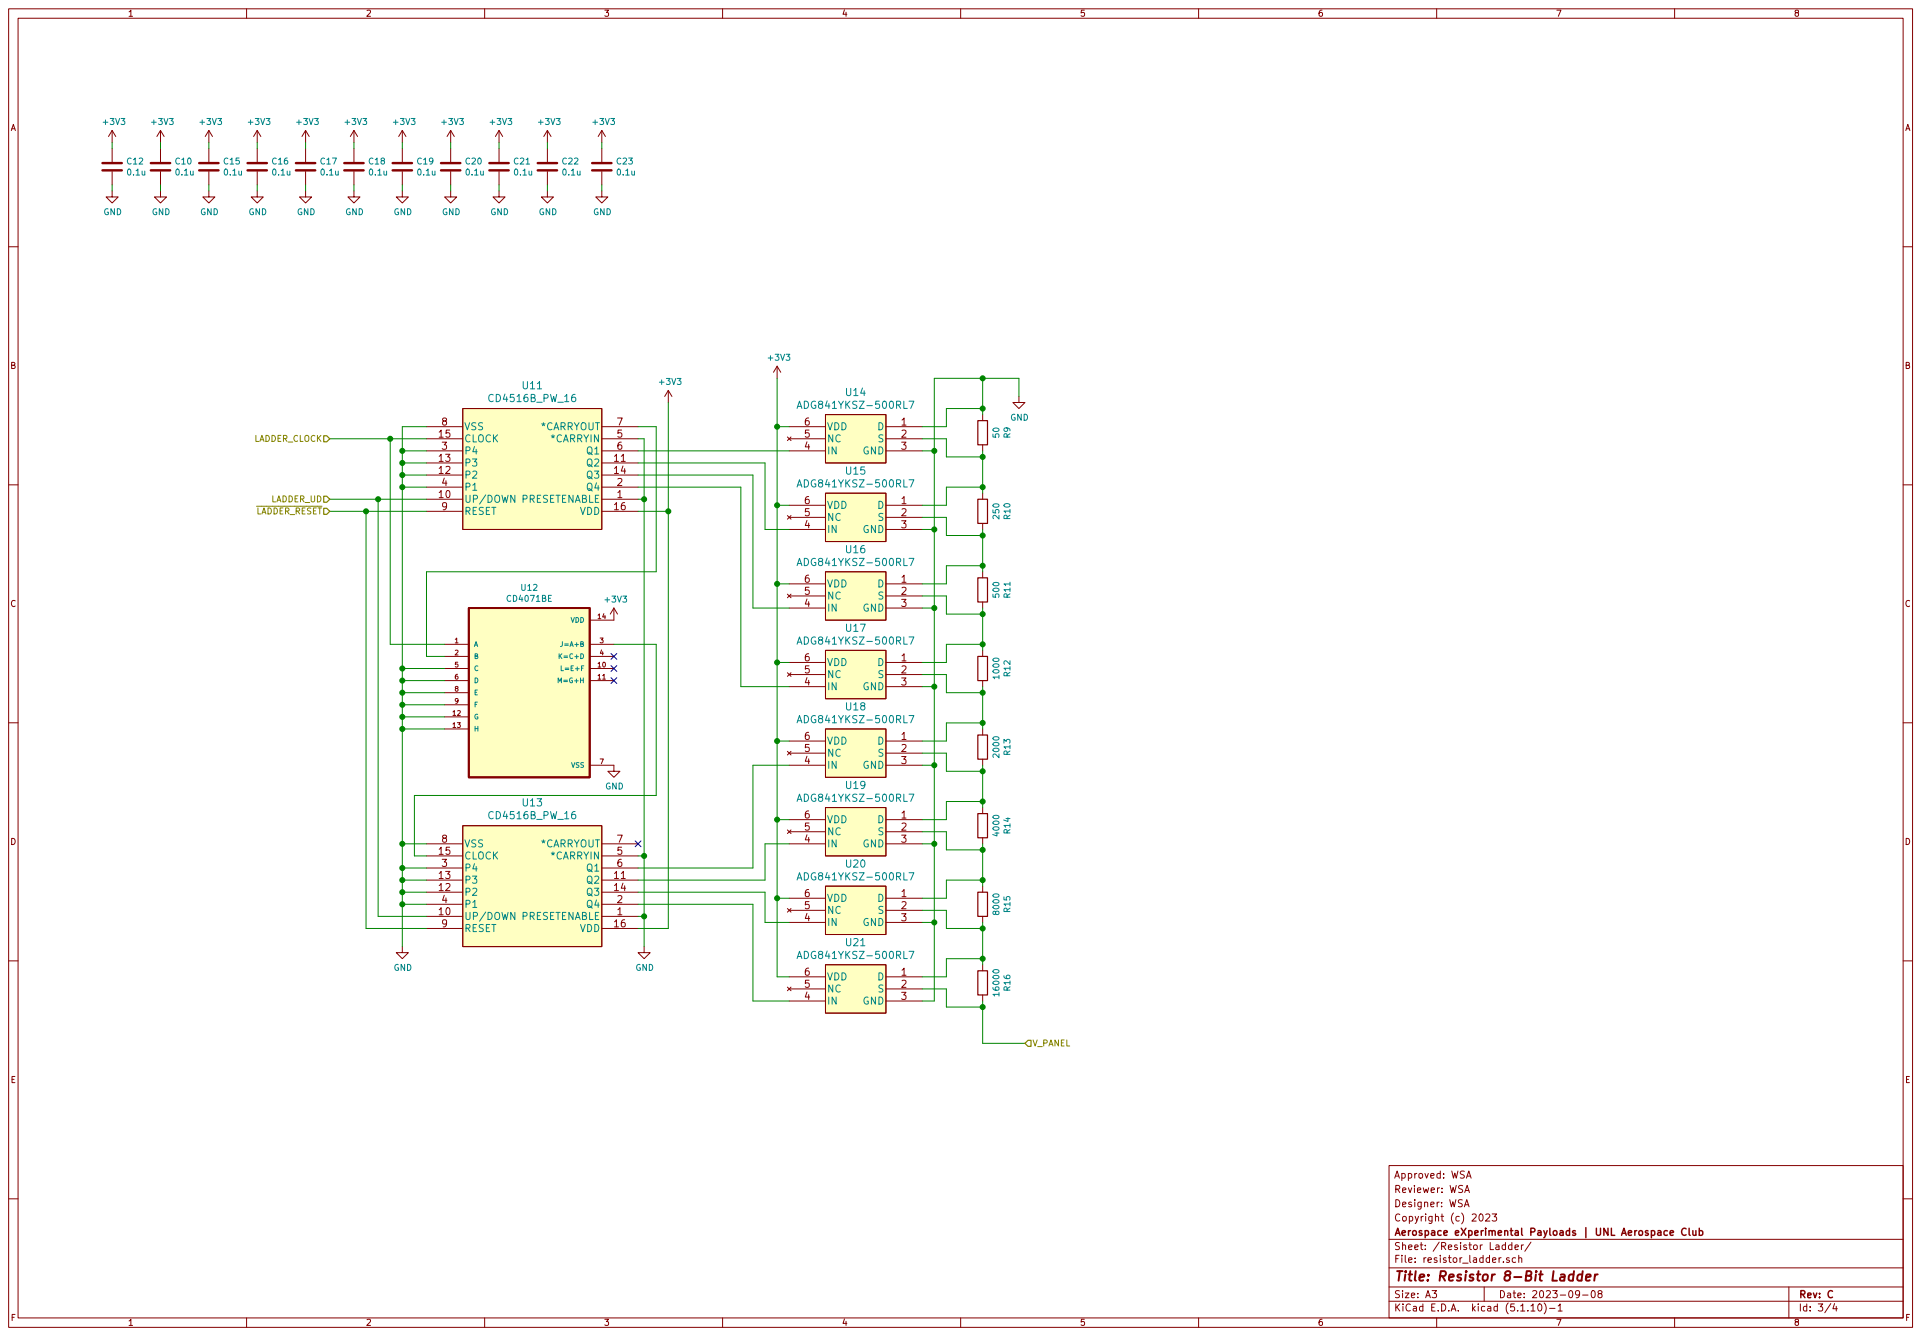
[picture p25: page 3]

Approved: WSA
Designer: WSA Reviewer: WSA

Copyright (c) 2023
File: resistor_ladder.sch Sheet: /Resistor Ladder/ Aerospace eXperimental Payloads | UNL Aerospace Club

Id: 3/4 Title: Resistor 8-Bit Ladder

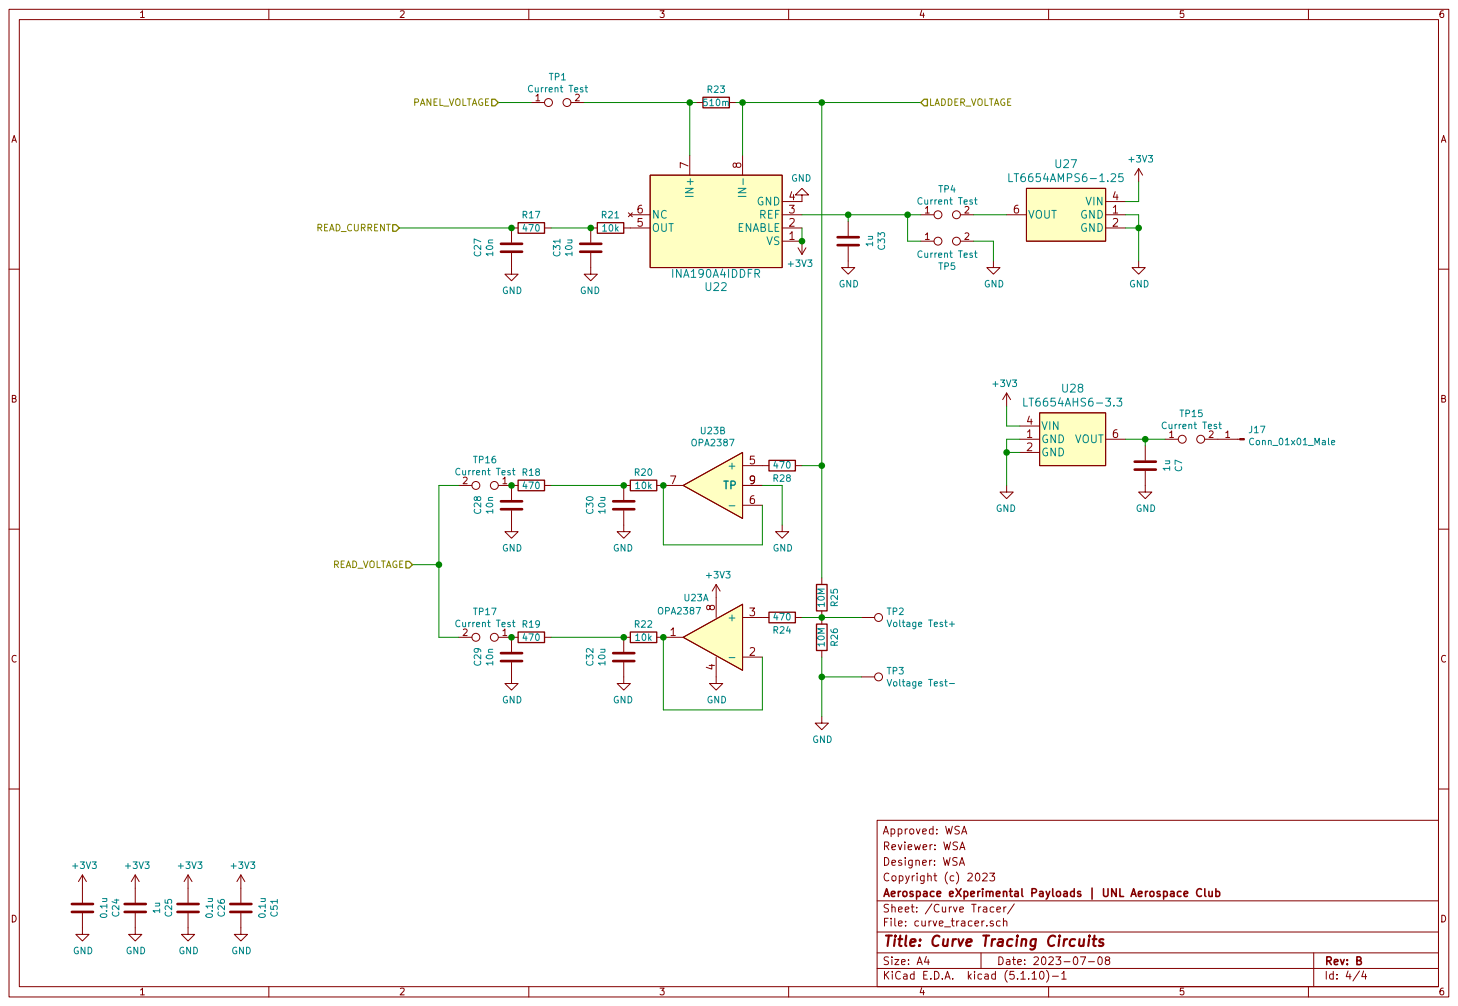
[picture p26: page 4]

Designer: WSA Reviewer: WSA

Copyright (c) 2023
File: curve_tracer.sch Sheet: /Curve Tracer/ Aerospace eXperimental Payloads | UNL Aerospace Club

Id: 4/4 Title: Curve Tracing Circuits

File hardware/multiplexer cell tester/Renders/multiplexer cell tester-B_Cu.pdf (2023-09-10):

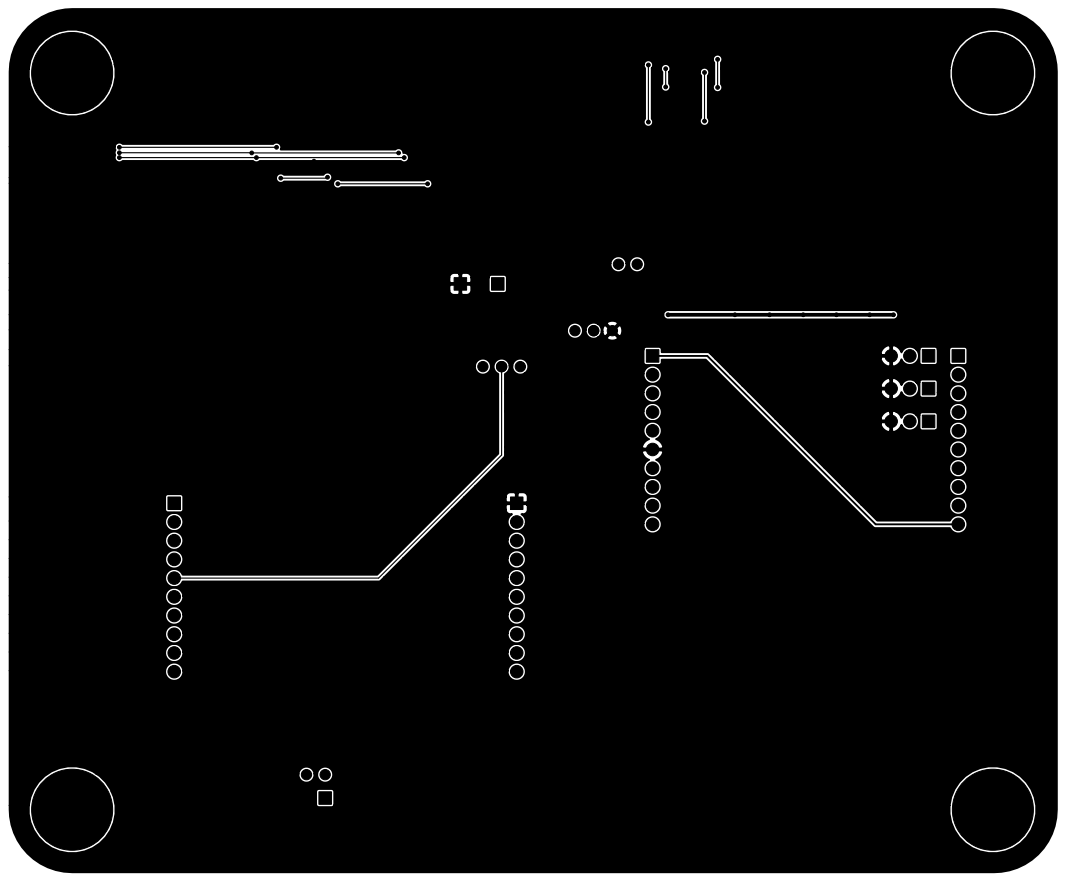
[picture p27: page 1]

Approved: WSA
Designer: WSA Reviewer: WSA

Copyright (c) 2023
File: multiplexer cell tester.kicad_pcb Sheet: Aerospace eXperimental Payloads | UNL Aerospace Club

Id: 1/1 Title: IV Curve Tracer for Ossila AM1.5 Solar Simulator

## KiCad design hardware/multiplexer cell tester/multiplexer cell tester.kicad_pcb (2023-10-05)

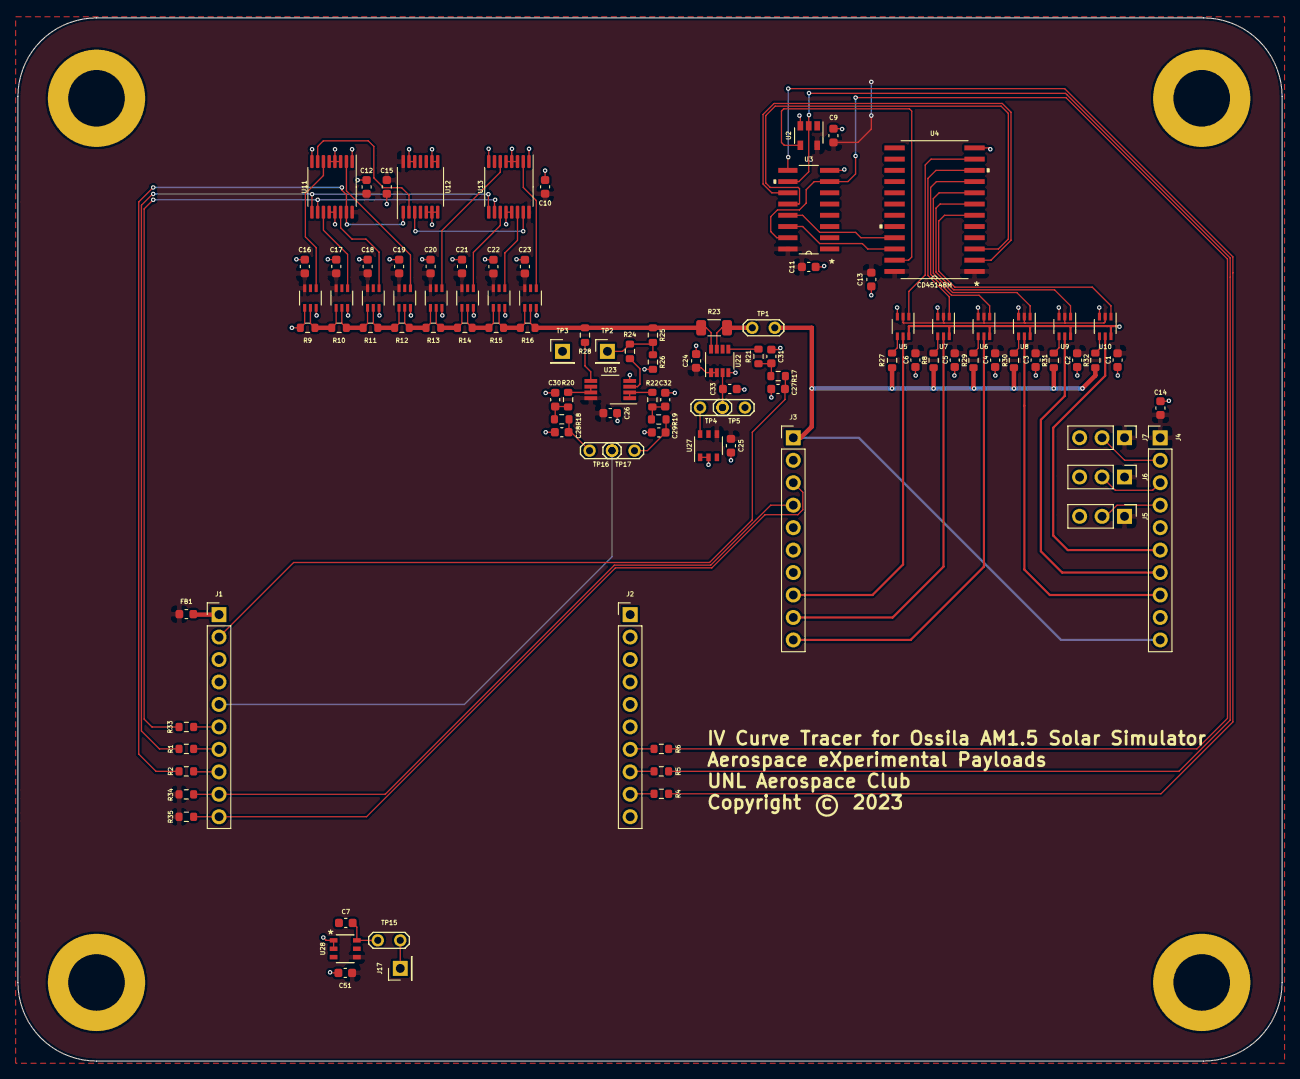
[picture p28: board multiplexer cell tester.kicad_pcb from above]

Board: 2 copper layers, 143.0 x 118.0 mm, 107 parts (0 on the bottom side), 80 nets.

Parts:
C1, C2, C3, C4, C5, C6, C9, C10, C11, C12, C13, C14, C15, C16, C17, C18, C19, C20, C21, C22, C23, C24, C26, C51: 0.1u; C_0603_1608Metric
C7, C25, C33: 1u; C_0603_1608Metric
C27, C28, C29: 10n; C_0603_1608Metric
C30, C31, C32: 10u; C_0603_1608Metric
FB1: Ferrite_Bead; L_0603_1608Metric
J1, J2, J3, J4: Conn_01x10_Female; PinHeader_1x10_P2.54mm_Vertical
J5: A2 Select; PinHeader_1x03_P2.54mm_Vertical
J6: A1 Select; PinHeader_1x03_P2.54mm_Vertical
J7: A0 Select; PinHeader_1x03_P2.54mm_Vertical
J17: Conn_01x01_Male; PinHeader_1x01_P2.54mm_Vertical
R1, R2, R4, R5, R6, R33: 100; R_0603_1608Metric
R8, R27, R29, R30, R31, R32: 400; R_0603_1608Metric
R9: 50; R_0603_1608Metric
R10: 250; R_0603_1608Metric
R11: 500; R_0603_1608Metric
R12: 1000; R_0603_1608Metric
R13: 2000; R_0603_1608Metric
R14: 4000; R_0603_1608Metric
R15: 8000; R_0603_1608Metric
R16: 16000; R_0603_1608Metric
R17, R18, R19, R24, R28: 470; R_0603_1608Metric
R20, R21, R22: 10k; R_0603_1608Metric
R23: 510m; R_1206_3216Metric
R25, R26: 10M; R_0603_1608Metric
R34, R35: 4k7; R_0603_1608Metric
TP1, TP4, TP5, TP15, TP16, TP17: Current Test; TestPoint_2Pads_Pitch2.54mm_Drill0.8mm
TP2: Voltage Test+; PinHeader_1x01_P2.54mm_Vertical
TP3: Voltage Test-; PinHeader_1x01_P2.54mm_Vertical
U2: SN74LVC1G14DRL; SOT-23-5
U3: CD4518BM96
U4: CD4514BM
U5, U6, U7, U8, U9, U10: ADG839YKSZ-REEL7
U11, U13: CD4516B_PW_16; TSSOP-16_4.4x5mm_P0.65mm
U12: CD4071BE; TSSOP-14_4.4x5mm_P0.65mm
U14, U15, U16, U17, U18, U19, U20, U21: ADG841YKSZ-500RL7
U22: INA190A4IDDFR
U23: OPA2387; VSSOP-8_3.0x3.0mm_P0.65mm
U27: LT6654AMPS6-1.25; LT6654AMPS6-1.25-TRMPBF
U28: LT6654AHS6-3.3; LT6654AHS6-3.3-TRMPBF

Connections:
10-19_CLOCK: R4.2, U3.9
+3V3: C1.1, C2.1, C3.1, C4.1, C5.1, C6.1, C9.1, C10.1, C11.1, C12.1, C13.1, C14.1, C15.1, C16.1, C17.1, C18.1, C19.1, C20.1, C21.1, C22.1, C23.1, C24.1, C25.1, C26.1, C51.1, FB1.1, J4.1, J5.1, J6.1, J7.1, R34.1, R35.1, U2.5, U3.16, U4.1, U4.24, U5.2, U6.2, U7.2, U8.2, U9.2, U10.2, U11.16, U12.14, U13.16, U14.6, U15.6, U16.6, U17.6, U18.6, U19.6, U20.6, U21.6, U22.1, U22.2, U23.8, U27.4, U28.4
/Curve Tracer/LADDER_VOLTAGE: R16.1, R23.1, R25.2, R28.2, U21.2, U22.8
/Curve Tracer/PANEL_VOLTAGE: J3.1, J4.10, R8.1, R27.1, R29.1, R30.1, R31.1, R32.1, TP1.1
/Perovskite Switches/SCL: J1.9, J3.4, R34.2
/Perovskite Switches/SDA: J1.10, J3.3, R35.2
A0: J4.2, J7.2
A1: J4.3, J6.2
A2: J4.4, J5.2
ENABLE_PANEL_SWITCH: R5.1, U2.2, U3.10
GND: C1.2, C2.2, C3.2, C4.2, C5.2, C6.2, C7.2, C9.2, C10.2, C11.2, C12.2, C13.2, C14.2, C15.2, C16.2, C17.2, C18.2, C19.2, C20.2, C21.2, C22.2, C23.2, C24.2, C25.2, C26.2, C27.2, C28.2, C29.2, C30.2, C31.2, C32.2, C33.2, C51.2, J2.1, J3.6, J5.3, J6.3, J7.3, R9.2, R26.1, TP3.1, TP5.2, U2.3, U3.8, U4.12, U5.3, U5.6, U6.3, U6.6, U7.3, U7.6, U8.3, U8.6, U9.3, U9.6, U10.3, U10.6, U11.1, U11.3, U11.4, U11.5, U11.8, U11.12, U11.13, U12.5, U12.6, U12.7, U12.8, U12.9, U12.12, U12.13, U13.1, U13.3, U13.4, U13.5, U13.8, U13.12, U13.13, U14.1, U14.3, U15.3, U16.3, U17.3, U18.3, U19.3, U20.3, U21.3, U22.4, U23.4, U27.1, U27.2, U28.1, U28.2
LADDER_CLOCK: R2.2, U11.15, U12.1
LADDER_UD: R33.2, U11.10, U13.10
unnamed: C7.1, TP15.1, U28.6
unnamed: C28.1, R18.1, TP16.1
unnamed: C29.1, R19.1, TP17.1
unnamed: C30.1, R18.2, R20.1
unnamed: C31.1, R17.2, R21.1
unnamed: C32.1, R19.2, R22.1
unnamed: C33.1, TP4.1, TP5.1, U22.3
unnamed: FB1.2, J1.1
unnamed: J1.6, R33.1
unnamed: J1.7, R1.1
unnamed: J1.8, R2.1
unnamed: J2.7, R6.2
unnamed: J2.8, R5.2
unnamed: J2.9, R4.1
unnamed: J3.8, U5.5
unnamed: J3.9, U7.5
unnamed: J3.10, U6.5
unnamed: J4.6, U10.5
unnamed: J4.7, U9.5
unnamed: J4.8, U8.5
unnamed: J17.1, TP15.2
unnamed: R8.2, U7.4
unnamed: R10.1, R11.2, U15.2, U16.1
unnamed: R9.1, R10.2, U14.2, U15.1
unnamed: R11.1, R12.2, U16.2, U17.1
unnamed: R12.1, R13.2, U17.2, U18.1
unnamed: R13.1, R14.2, U18.2, U19.1
unnamed: R14.1, R15.2, U19.2, U20.1
unnamed: R15.1, R16.2, U20.2, U21.1
unnamed: R20.2, U23.6, U23.7
unnamed: R21.2, U22.5
unnamed: R22.2, U23.1, U23.2
unnamed: R23.2, TP1.2, U22.7
unnamed: R24.1, U23.3
unnamed: R24.2, R25.1, R26.2, TP2.1
unnamed: R27.2, U5.4
unnamed: R28.1, U23.5
unnamed: R29.2, U6.4
unnamed: R30.2, U8.4
unnamed: R31.2, U9.4
unnamed: R32.2, U10.4
unnamed: TP4.2, U27.6
unnamed: U2.4, U4.23
unnamed: U3.11, U4.2
unnamed: U3.12, U4.3
unnamed: U3.13, U4.21
unnamed: U3.14, U4.22
unnamed: U4.7, U9.1
unnamed: U4.8, U8.1
unnamed: U4.9, U6.1
unnamed: U4.10, U7.1
unnamed: U4.11, U5.1
unnamed: U4.6, U10.1
unnamed: U11.2, U17.4
unnamed: U11.6, U14.4
unnamed: U11.7, U12.2
unnamed: U11.11, U15.4
unnamed: U11.14, U16.4
unnamed: U12.3, U13.15
unnamed: U13.2, U21.4
unnamed: U13.6, U18.4
unnamed: U13.11, U19.4
unnamed: U13.14, U20.4
READ_CURRENT: C27.1, J1.2, R17.1
READ_VOLTAGE: J1.5, TP16.2, TP17.2
RESET_PANEL_SWITCH: R6.1, U3.7, U3.15
~LADDER_RESET: R1.2, U11.9, U13.9

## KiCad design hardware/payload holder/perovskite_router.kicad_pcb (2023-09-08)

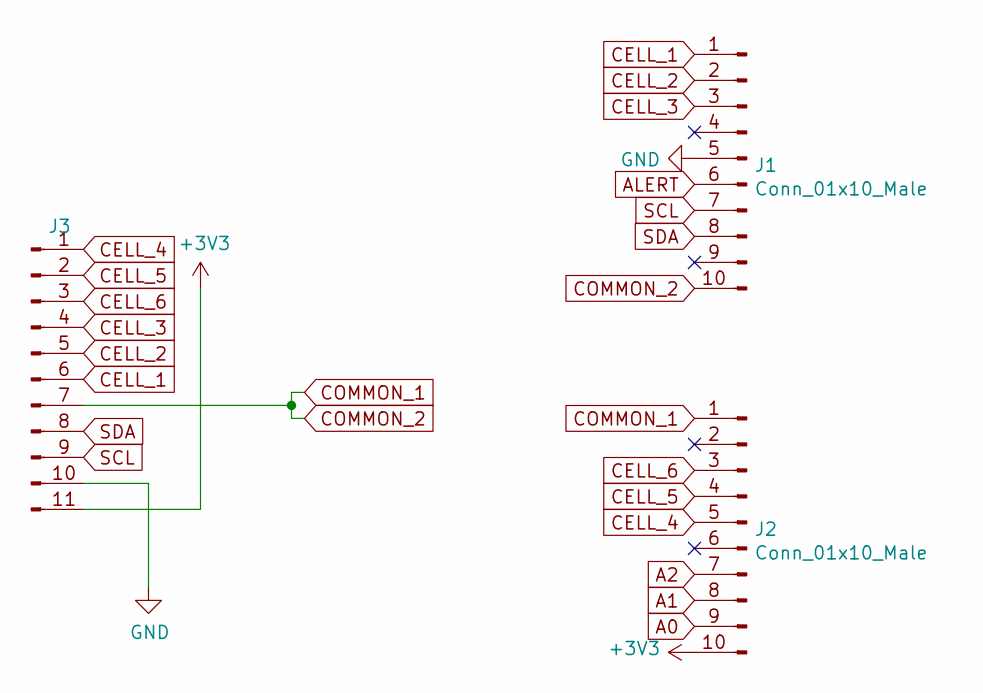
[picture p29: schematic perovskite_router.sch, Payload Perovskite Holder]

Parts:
J1, J2: Conn_01x10_Male; PinHeader_1x10_P2.54mm_Vertical
J3: Conn_01x11_Male; PinHeader_1x11_P1.27mm_Vertical

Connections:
+3V3: J2.10, J3.11
A0: J2.9
A1: J2.8
A2: J2.7
ALERT: J1.6
CELL_1: J1.1, J3.6
CELL_2: J1.2, J3.5
CELL_3: J1.3, J3.4
CELL_4: J2.5, J3.1
CELL_5: J2.4, J3.2
CELL_6: J2.3, J3.3
COMMON_1: J1.10, J2.1, J3.7
GND: J1.5, J3.10
SCL: J1.7, J3.9
SDA: J1.8, J3.8

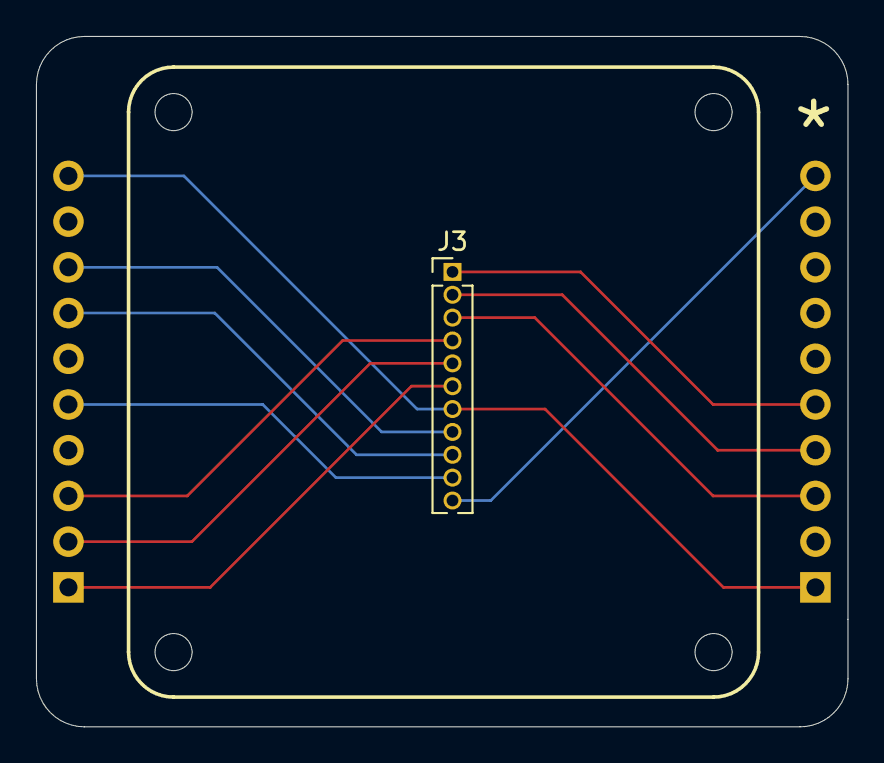
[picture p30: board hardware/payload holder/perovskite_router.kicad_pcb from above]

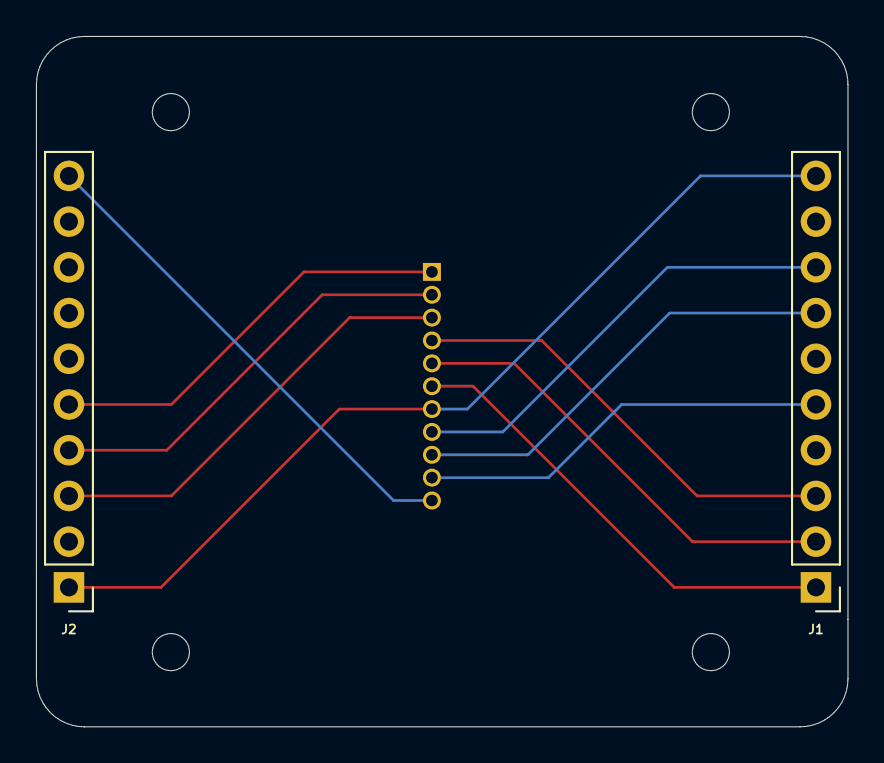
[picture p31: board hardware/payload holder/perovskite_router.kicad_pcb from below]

Board: 2 copper layers, 45.1 x 38.4 mm, 3 parts (2 on the bottom side), 11 nets.

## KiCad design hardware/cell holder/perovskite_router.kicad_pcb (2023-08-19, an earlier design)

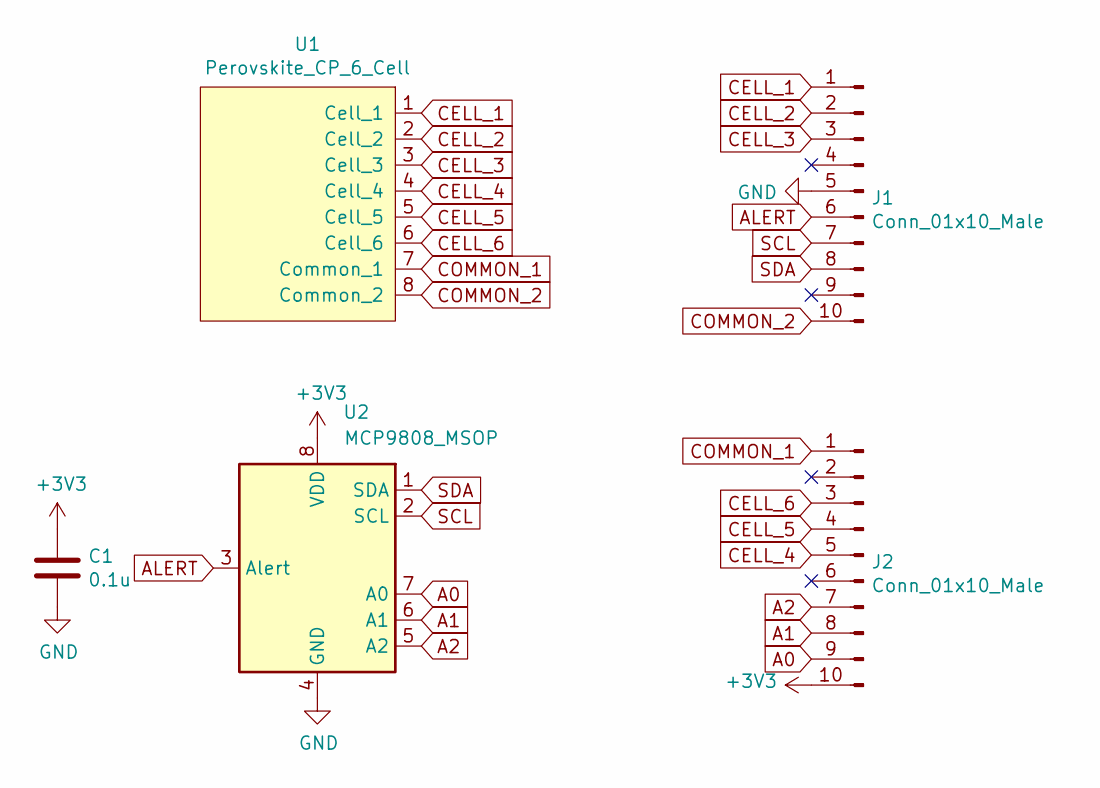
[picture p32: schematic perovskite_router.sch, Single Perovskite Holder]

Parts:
C1: 0.1u; C_0603_1608Metric_Pad1.08x0.95mm_HandSolder
J1, J2: Conn_01x10_Male; PinHeader_1x10_P2.54mm_Vertical
U1: Perovskite_CP_6_Cell; Perovskite
U2: MCP9808_MSOP; MCP9804_With_Hole

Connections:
+3V3: C1.1, J2.10, U2.8 (VDD)
A0: J2.9, U2.7 (A0)
A1: J2.8, U2.6 (A1)
A2: J2.7, U2.5 (A2)
ALERT: J1.6, U2.3 (Alert)
CELL_1: J1.1, U1.1 (Cell_1)
CELL_2: J1.2, U1.2 (Cell_2)
CELL_3: J1.3, U1.3 (Cell_3)
CELL_4: J2.5, U1.4 (Cell_4)
CELL_5: J2.4, U1.5 (Cell_5)
CELL_6: J2.3, U1.6 (Cell_6)
COMMON_1: J2.1, U1.7 (Common_1)
COMMON_2: J1.10, U1.8 (Common_2)
GND: C1.2, J1.5, U2.4 (GND)
SCL: J1.7, U2.2 (SCL)
SDA: J1.8, U2.1 (SDA)

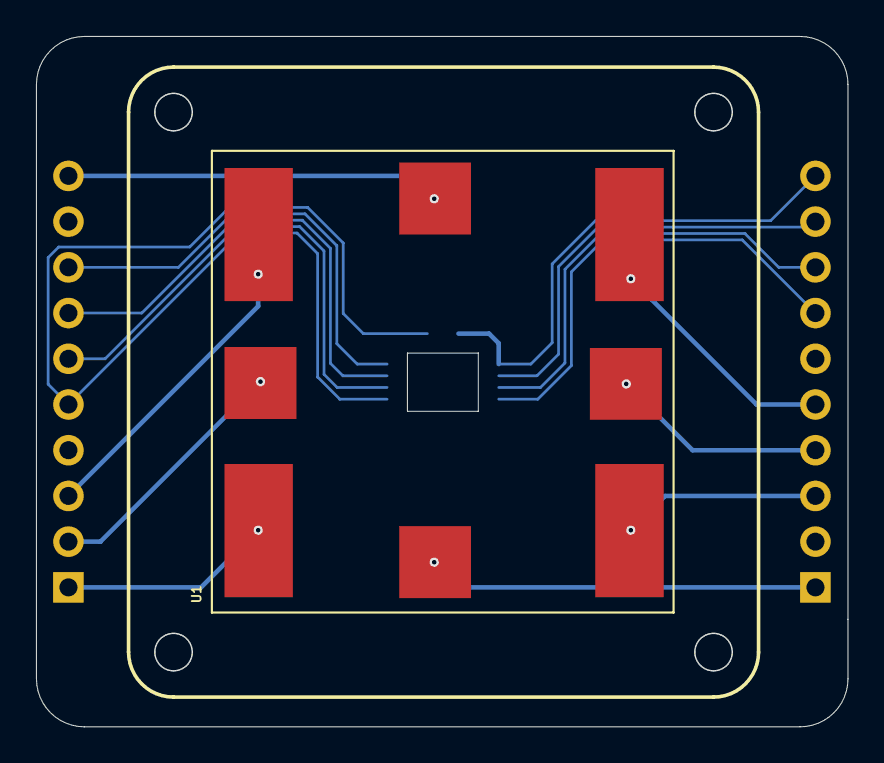
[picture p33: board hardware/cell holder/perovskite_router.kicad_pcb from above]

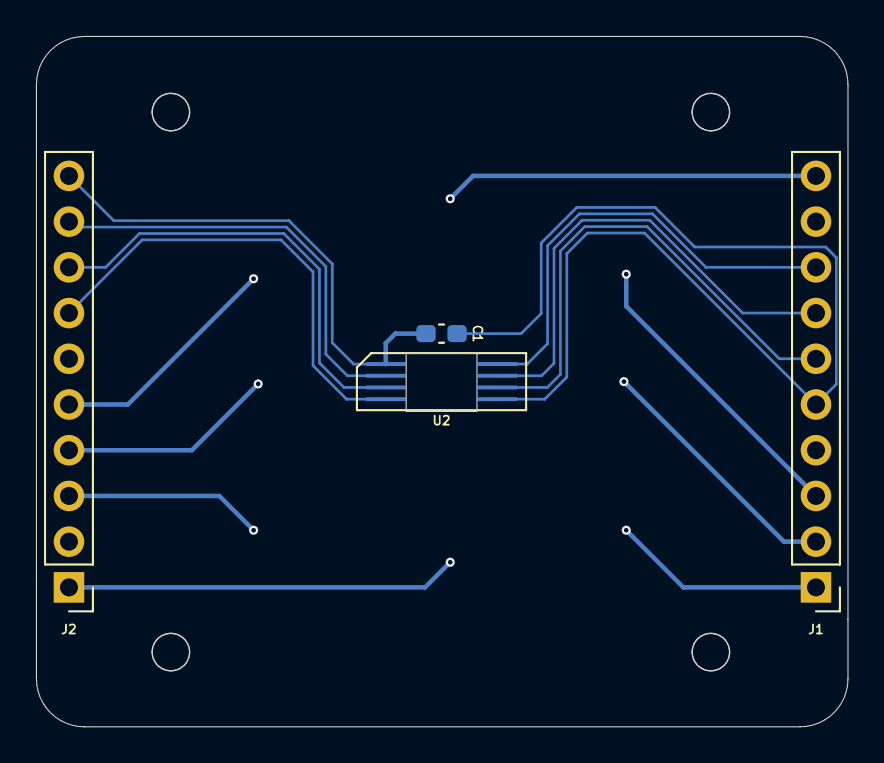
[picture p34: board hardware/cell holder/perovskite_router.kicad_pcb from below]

Board: 2 copper layers, 45.1 x 38.4 mm, 5 parts (4 on the bottom side), 16 nets.

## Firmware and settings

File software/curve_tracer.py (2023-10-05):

import sys
import threading
import time
import tkinter
from tkinter import messagebox
import os
import datetime
import matplotlib.pyplot as plt
import serial
from matplotlib.backends.backend_tkagg import FigureCanvasTkAgg
from matplotlib.figure import Figure
from serial import SerialException
from serial.tools import list_ports
import pandas as pd

SMALL_SIZE = 8
MEDIUM_SIZE = 10
BIGGER_SIZE = 12

plt.rc('font', size=SMALL_SIZE)  # controls default text sizes
plt.rc('axes', titlesize=SMALL_SIZE)  # fontsize of the axes title
plt.rc('axes', labelsize=SMALL_SIZE)  # fontsize of the x and y labels
plt.rc('xtick', labelsize=SMALL_SIZE)  # fontsize of the tick labels
plt.rc('ytick', labelsize=SMALL_SIZE)  # fontsize of the tick labels
plt.rc('legend', fontsize=SMALL_SIZE)  # legend fontsize
plt.rc('figure', titlesize=BIGGER_SIZE)  # fontsize of the figure title
fig_color = '#%02x%02x%02x' % (240, 240, 237)

curve_points_i = [[] for _ in range(6)]
curve_points_v = [[] for _ in range(6)]
curve_points_j = [[] for _ in range(6)]
curve_points_p = [[] for _ in range(6)]
curve_point = [[] for _ in range(6)]
current_panel = 1
current_direction = False

direction_text = ["Reverse", "Forward"]


def clear_plot():
    plot1.clear()


def plot_curve(curve_i):
    global current_direction
    plot1.set_title("Perovskite J-V Curve")
    plot1.set_xlabel("Voltage (V)")
    plot1.set_ylabel("Current Density (mA cm^-2)")
    plot1.plot(curve_points_v[curve_i], curve_points_j[curve_i], label=f"Pixel {curve_i} {direction_text[int(current_direction)]}")
    canvas.draw()


def adc_to_voltage(adc_code, ref_voltage=3.3, max_bin=2**12, gain=0.5, bias_voltage=0.0):
    return (((ref_voltage * adc_code) / float(max_bin - 1)) - bias_voltage) / gain


def adc_to_current(adc_code, gain=50.0, ref_voltage=1.2, max_bin=2**12, sense_res=0.01):
    v = adc_to_voltage(adc_code, ref_voltage=ref_voltage, max_bin=max_bin, gain=1)
    return ((v / gain) / sense_res) * 1000


def read_curve():
    clear_plot()
    overall_summary = pd.DataFrame()
    for dirs in range(2):
        if dirs:
            reverse_trace_direction()
        for i in range(6):
            curve_point[i].clear()
            curve_points_v[i].clear()
            curve_points_i[i].clear()
            curve_points_j[i].clear()
            curve_points_p[i].clear()
            pixel_area_value = float(1 if pixel_area.get() == "" else pixel_area.get())
            if pixel_area_value < 0:
                pixel_area_value = 1e-7
            irradiance_value = float(100 if irradiance.get() == "" else irradiance.get())
            if irradiance_value < 0:
                irradiance_value = 1e-7
            msp430_port.write(b'C')
            start_time = time.time()
            while len(curve_point[i]) != 256:
                reading = ''.join(map(chr, msp430_port.readline().strip())).split(' ')
                curve_point[i].append(int(reading[0]))
                curve_points_v[i].append(adc_to_voltage(abs(int(reading[1])), ref_voltage=3.29, bias_voltage=0.0, max_bin=2**12))
                curve_points_i[i].append(adc_to_current(abs(int(reading[2])), ref_voltage=3.29, gain=200.0, sense_res=0.51, max_bin=2**12))
                curve_points_j[i].append(curve_points_i[i][-1] / pixel_area_value)
                curve_points_p[i].append(curve_points_v[i][-1] * curve_points_i[i][-1])
            temperature_reading = float(msp430_port.readline().strip()) / 100.0
            end_time = time.time()
            sc_cond.config(text=f"Short Circuit: {curve_points_v[i][-1]:.4f} V | {curve_points_i[i][-1]:.4f} mA")
            oc_cond.config(text=f"Open Circuit: {curve_points_v[i][0]:.4f} V | {curve_points_i[i][0]:.4f} mA")
            curve_time.config(text=f"Trace Time: {(end_time - start_time) * 10**3:.4f} ms")
            # temp_label.config(text=f"Panel Temperature: {temperature_reading} \u00b0C")
            plot_curve(i)
            mpp_idx = max(enumerate(curve_points_p[i]), key=lambda x: x[1])[0]
            voc = curve_points_v[i][0]
            isc = curve_points_i[i][-1]
            mpp_v = curve_points_v[i][mpp_idx]
            mpp_i = curve_points_i[i][mpp_idx]
            mpp_p = mpp_v * mpp_i
            ff = (mpp_v * mpp_i) / ((voc * isc) + 1e-7)
            eff = (mpp_p / pixel_area_value) / irradiance_value
            test_time = datetime.datetime.now()
            summary_df = pd.DataFrame(
                [test_time, panel_name.get(), i, pixel_area_value, irradiance_value, temperature_reading, voc, isc, mpp_v, mpp_i, mpp_p, ff, eff, direction_text[dirs]],
                index=["Time", "ID", "Pixel", "Pixel Area", "Irradiance", "Panel Temperature", "Voc", "Isc", "Vmp", "Imp", "Pmp", "FF", "Eff", "Dir"]
            )
            overall_summary = pd.concat([overall_summary, summary_df], axis=1)
            if save_curves.get():
                if panel_name.get() != "":
                    root_dir = os.path.join(output_path, panel_name.get())
                    if not os.path.exists(root_dir):
                        os.mkdir(root_dir)
                    curve_output_path = os.path.join(root_dir,
                                                     f'curve_{temperature_reading}_{get_panel_int()}_{direction_text[dirs]}' + '.xlsx')
                else:
                    curve_output_path = os.path.join(output_path,
                                                     f'curve_{temperature_reading}_{get_panel_int()}_{direction_text[dirs]}' + '.xlsx')
                curve_df = pd.DataFrame([curve_points_v[i], curve_points_i[i], curve_points_j[i], curve_points_p[i]],
                                        index=['Voltage', 'Current', 'Current Density', 'Power']).transpose()
                writer = pd.ExcelWriter(curve_output_path, engine='xlsxwriter')
                frames = {'Summary': summary_df, 'Data': curve_df}
                # now loop thru and put each on a specific sheet
                for sheet, frame in frames.items():  # .use .items for python 3.X
                    frame.to_excel(writer, sheet_name=sheet)
                # critical last step
                writer.close()
            next_panel()
            plot1.legend()
            canvas.draw()
        if save_curves.get():
            if panel_name.get() != "":
                root_dir = os.path.join(output_path, panel_name.get())
                if not os.path.exists(root_dir):
                    os.mkdir(root_dir)
                curve_image_path = os.path.join(root_dir, f'{panel_name.get()}_plotted_{direction_text[dirs]}.png')
                summary_output_path = os.path.join(root_dir, f"{panel_name.get()}_summary_{direction_text[dirs]}.xlsx")
            else:
                curve_image_path = os.path.join(output_path, f'all_plotted_{direction_text[dirs]}.png')
                summary_output_path = os.path.join(output_path, f"all_summary_{direction_text[dirs]}.xlsx")
            fig.savefig(curve_image_path, dpi=500)
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

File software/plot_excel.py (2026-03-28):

import numpy as np
import pandas as pd
import os
import matplotlib.pyplot as plt
import scienceplots
plt.style.use(['science', 'ieee', 'high-vis'])
xticks = np.arange(0, 1.2, 0.2)
xticks = [float(f'{x:1.1f}') for x in xticks]

x018 = r"C:\Users\Walker Arce\Documents\GitHub\Perovskite-Curve-Tracer\software\curves\3. Final Round\X018_LM"
files = os.listdir(x018)
files = [f for f in files if "curve" in f]
forward_files = [f for f in files if "Forward" in f]
reverse_files = [f for f in files if "Reverse" in f]

pixel_number = 0
for f in forward_files:
    test = pd.read_excel(os.path.join(x018, f), sheet_name="Data")
    if pixel_number == 0:
        plt.plot(test['Voltage'][40:], test['Current Density'][40:], label=f"Pixel {pixel_number}")
    else:
        plt.plot(test['Voltage'], test['Current Density'], label=f"Pixel {pixel_number}")
    pixel_number += 1
plt.ylabel("Current Density ($mA/cm^{-2}$)")
plt.xlabel("Voltage ($V$)")
plt.title("X018 Forward JV Curves")
plt.xticks(xticks, labels=xticks)
plt.legend()
plt.savefig("x018_forward.png", dpi=300, bbox_inches="tight")
plt.clf()

pixel_number = 0
for f in reverse_files:
    test = pd.read_excel(os.path.join(x018, f), sheet_name="Data")
    plt.plot(test['Voltage'], test['Current Density'], label=f"Pixel {pixel_number}")
    pixel_number += 1
plt.ylabel("Current Density ($mA/cm^{-2}$)")
plt.xlabel("Voltage ($V$)")
plt.title("X018 Reverse JV Curves")
plt.xticks(xticks, labels=xticks)
plt.legend()
plt.savefig("x018_reverse.png", dpi=300, bbox_inches="tight")
plt.clf()

leakage = r"C:\Users\Walker Arce\Documents\GitHub\Perovskite-Curve-Tracer\software\curves\X031_ShuntTest_500"
files = os.listdir(leakage)
files = [f for f in files if "curve" in f]
forward_files = [f for f in files if "Forward" in f]
reverse_files = [f for f in files if "Reverse" in f]

pixel_number = 0
for f in forward_files:
    test = pd.read_excel(os.path.join(leakage, f), sheet_name="Data")
    if pixel_number == 0:
        plt.plot(test['Voltage'][40:], test['Current Density'][40:], label=f"Pixel {pixel_number}")
    else:
        plt.plot(test['Voltage'], test['Current Density'], label=f"Pixel {pixel_number}")
    pixel_number += 1
plt.ylabel("Current Density ($mA/cm^{-2}$)")
plt.xlabel("Voltage ($V$)")
plt.title("X032 Forward JV Curves")
plt.xticks(xticks, labels=xticks)
plt.legend()
plt.savefig("leakage_forward.png", dpi=300, bbox_inches="tight")
plt.clf()

pixel_number = 0
for f in reverse_files:
    test = pd.read_excel(os.path.join(leakage, f), sheet_name="Data")
    plt.plot(test['Voltage'], test['Current Density'], label=f"Pixel {pixel_number}")
    pixel_number += 1
plt.ylabel("Current Density ($mA/cm^{-2}$)")
plt.xlabel("Voltage ($V$)")
plt.title("X032 Reverse JV Curves")
plt.xticks(xticks, labels=xticks)
plt.legend()
plt.savefig("leakage_reverse.png", dpi=300, bbox_inches="tight")
plt.clf()

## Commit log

2023-08-02 Update curve_tracer.py
    - Update for new curve tracer
    - Add current density conversion
    - Add folder selection and creation
2023-08-19 Update curve_tracer.py
    - Trace all pixels and show data on plot
    - Calculate other metrics
    - Find maximum power point
    - Export image of plot
2023-08-19 Add hardware and reorganize
    [0781710004.step, 1SkiteHolder.DXF, ADS131M04IPWR.step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]
2023-08-19 Fix some bugs
    - Add epsilon to prevent divide by zero
    - Add power data
    - Fix xlsxwriter close
    - Make sure canvas updates during tracing
    [curve_0.0_0.csv, curve_0.0_1.csv, curve_0.0_2.csv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]
2023-08-20 Create step files for holder
    [arm.step, body.step]
2023-08-24 Updating curve tracer
    - Remove unused circuits
    - Update gerbers and renders
    [curve_tracer.sch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]
2023-09-08 Create holders
    - Created holders for the payload
    - Sliced holders for testing
    [arm_v2.stl, body_v2.stl, curve_0.0_0.csv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]
2023-09-08 Update design to handle wire harnesses
    [payload_holder_p1.stl, payload_holder_p2.stl, payload_holder_p3.stl]
2023-09-08 Add payload holder
    Added example of different holder for perovskites
    [1SkiteHolder.DXF, MCP9801-M_MS.stp, Perovskite v2.step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]
2023-09-10 Finalized curve tracer
    [CD4071BE.step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]
2023-10-05 Final testing
    - Finalize hardware, add output capacitor to voltage reference
    - Add curve data
    - Update curve tracing software to newest hardware
    [1764_08222023_summary.xlsx, 1764_08232023_2_summary.xlsx, 1764_08232023_summary.xlsx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]
2023-10-09 Prefinal testing
    - 0.3NM torque tests
    - 0.7NM torque tests
    - Coverglass degredation tests
    [100623_14_44_degredations_summary_Forward.xlsx, 100623_14_44_degredations_summary_Reverse.xlsx, 1008_21_15_degredation_summary_Forward.xlsx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]
2023-10-12 Testing for A48 Problem
    - Disconnecting SDA and SCL fixed problem
    [A48_I2C disconect_NO_light_summary_Forward.xlsx, A48_I2C disconect_NO_light_summary_Reverse.xlsx, A48_I2C disconect_summary_Forward.xlsx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]
2023-10-17 Tested final perovskites
    [Working Pixels.xlsx, X---_LM_UE_summary_Forward.xlsx, X---_LM_UE_summary_Reverse.xlsx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]
2023-10-17 Move data into same folder
    [100623_14_44_degredations_summary_Forward.xlsx, 100623_14_44_degredations_summary_Reverse.xlsx, 1008_21_15_degredation_summary_Forward.xlsx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]
2023-10-17 Create folders for old data
    [100623_14_44_degredations_summary_Forward.xlsx, 100623_14_44_degredations_summary_Reverse.xlsx, 1008_21_15_degredation_summary_Forward.xlsx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]
2023-10-19 Tested final payloads
    [A001_Payload1_summary_Forward.xlsx, A001_Payload1_summary_Reverse.xlsx, A012_Payload2_summary_Forward.xlsx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]
2023-11-05 Update curve results
    [A001_Payload1_summary_Forward.xlsx, A001_Payload1_summary_Reverse.xlsx, A012_Payload2_summary_Forward.xlsx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]
2025-10-29 Working on paper
    [tables.xlsx]
2025-10-31 Finish draft of paper
    [tables.xlsx]
2026-03-28 Create figures
    [X018_NLR_UNL.xlsx, curve_0.0_0_Reverse.xlsx, curve_0.0_1_Reverse.xlsx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]

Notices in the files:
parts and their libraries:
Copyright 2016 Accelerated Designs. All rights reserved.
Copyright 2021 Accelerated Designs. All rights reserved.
